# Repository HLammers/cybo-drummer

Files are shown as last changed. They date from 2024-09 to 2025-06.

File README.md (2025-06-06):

<header>


# Cybo-Drummer

**Humanize those drum computers!**

&copy; 2024&ndash;2025 Harm Lammers
</header>
<main>


# Introduction

The situation was that I owned an electronic drum kit and a bunch of drum computers. My dream was to play those drum computers from my drum kit, so I went searching for a way to do just that. It turned out that I couldn&rsquo;t find any software or hardware solution that would give easy-to-use experience with the flexibility to change the mapping as you change a program on a drum module.

That was April 2024, when Cybo-Drummer was born: I decided to develop my own solution. The first prototype on a breadboard took a couple of months build and showed that it could work, but I had a lot to learn: programming in MicroPython, designing PCBs, (re)writing display drivers and a lot more. Also, when Cybo-Drummer started to take shape, it turned out to be a much more complex project than I had anticipated&hellip;

In November 2024 the second prototype was finally ready and I decided to publish it as an open source project. I received several enthausiast responses of people liking the idea, but no one else tried building their own Cybo-Drummer as far as I can tell &ndash; that is no surprise, because the project was still very rough around the edges, with its ad hoc hardware design, no case, a sluggy graphic user interface and an overly complex workflow.

Now, in June 2025 it&rsquo;s time to launch the third prototype. This time everything as been redesigned: new hardware (now based on the more powerful Raspberry Pi Pico 2) in a 3D printed case, an almost completely redesigned user interface (now with icons and a font specially designed for Cybo-Drummer!) and a simplified, yet improved workflow, making it much more intuitive to use, yet virtually as powerful as the previous prototype. It also introduces some neat new features, like velocity layers and tools to easily assign note series to toms and scales/modes and chords to multipad triggers.

With the thrid prototype Cybo-Drummer has reached a state where it does what it has to do. There are still [a few things to be done](#development-roadmap) before reaching version 1.0 (but all things that could be solved with firmware updates). MIDI learn, for example still needs to be refined, better tested and documented. A big inprovement still to come is adding USB MIDI support. Before version 1.23 (released on 31 May 2024) MicroPython didn&rsquo;t support MIDI over USB and even now no one figured out yet how (in MicroPython) to set up the USB MIDI descriptors, such that multiple MIDI ports (over the same USB connection) show up with different port names in the host (see the [MicroPython GitHub discussion](https://github.com/orgs/micropython/discussions/16435) &ndash; if you know how this works, your input is appreciated!)

Are you an experienced drummer with a fascination for synthesized drum sounds? (I&rsquo;ve only started my drumming journey in April 2023 and too much of my time has gone into developing Cybo-Drummer instead of practizing&hellip;) I&rsquo;d love to hear how you experience using Cybo-Drummer. Does it work for you? What would you change? What features are you missing?

> [!NOTE]
> Please use the [issues tab](https://github.com/HLammers/cybo-drummer/issues) to report bug and other issues, or the [discussion tab](https://github.com/HLammers/cybo-drummer/discussions) to discuss anything else.
>
> Of course I&rsquo;m open for collaboration. Just let me know how you think you can contribute!

# Overview

Cybo-Drummer is a MIDI router/mapper with 6 input ports and 6 output ports, specially designed for mapping drum triggers (electronic drum kits&rsquo; modules or brains) to drum computers. Since there is no standard for the MIDI messages sent by drum kits, nor the messages received by drum computers, Cybo-Drummer offers a flexible way of mapping the one to the other.

Cybo-Drummer operates at two distinct levels, each running on its own processor core, as shown by the dashed line in the diagram below:

<div align="center">

</div>

<i>Diagram showing Cybo-Drummer&rsquo;s inner workings. The icons in the corners of the green and orange shapes refer to the respective <a href="USER_MANUAL.md#pages-and-sub-pages">pages</a> in Cybo-Drummer&rsquo;s graphic user interface.</i>

The top level (with the green and orange shapes in the diagram above) manages all definitions, user interaction (buttons and knobs) and the graphic user interface. Some of these definitions are global and the same for all programs (green shapes and arrows), while other definitions (orange shapes and arrows) change when selecting one of the up to 2,600 programs (26 banks of 100 programs).

The bottom level (with the purple shapes and arrows in the diagram above) does its work hidden to the user. Here sits the actual router that routes MIDI data from input ports to output ports &ndash; transformed if neccessary. It is optimized to do as little as possible, to minimize latency.

No interaction takes place between the top and the bottom layer, except if a program is changed or a set-up definition is modified &ndash; this resets the router, rebuilding each route based on the definitions from the top layer.

# Features

## Key Features

* Real-time (low latency) mapping of up to 6 MIDI input devices (drum kits, drum triggers, multipad devices, etc.) to up to 6 MIDI output devices (drum computers, samplers, synthesizers, etc.)
* Combine multiple input devices in a single setup
* Define up to 2,600 programs (26 banks of 100 programs) to easily swich between different output devices and voices
* Combine multiple output devices in one program
* Layer multiple voices from the same or different output devices, including advanced layering techniques based on velocity layers and transition curves
* Set trigger dependency to cc value (a common way for drum modules/brains to distinguish between open and closed hihat)
* Adjust velocity dynamics (threshold, curve, minimum velocity, maximum velocity)
* Adjust how to send note off (off, pulse, fixed delay or a toggle on/off effect)
* Send program change and/or bank select commands to output devices on program change
* Quickly set up toms to the same output device/voice, but with different notes, based on intervals or chords
* Quickly assign notes to the pads of a multipad trigger to different notes, based on scales/modes or to chords (or a combination of both)
* Basic MIDI monitor

## Hardware

* 6 MIDI input ports (5-pin DIN)
* 6 MIDI output ports (5-pin DIN)
* 2.2 inch colour display (220×176 pixels)
* 2 knobs (rotary encoders) and 3 buttons to interact with Cybo-Drummer&rsquo;s graphic user interface
* Power over micro USB or 5V DC power supply
* Option to mount onto drum rack using a standard mounting plate with screw holes spaced 70×100mm (as often used for drum modules/brains and multipads)

# Documentation

For indept documentation on Cybo-Drummer, see the following files:

* [User Manual](USER_MANUAL.md)
* [Building Instructions](BUILDING_INSTRUCTIONS.md)
* [Example Presets](EXAMPLE_PRESETS.md)
* [Development Roadmap](TO_DO.md)

> [!NOTE]
> **<ins>Cybo-Drummer Terminology</ins>**
>
> Since there is no universal terminology used by all manufacturers of electronic drum equipment and drum computers, or that describes all possible combinations of equipment that could be used, a choice had to be made to use the following terminology for Cybo-Drummer:
>
> <table>
> <tr><td><b><i>Input device</i></b></td><td>A drum kit, drum triggers, multipad device, keyboard or other device which exists of multiple <i>triggers</i> and outputs MIDI data</td></tr>
> <tr><td><b><i>Trigger</i></b></td><td>A drum pad, trigger or similar element of an electronic drum kit or other type of <i>input device</i>; a trigger has one or more <i>zones/layers</i></td></tr>
> <tr><td><b><i>Zone/layer</i></b></td><td>A zone or a layer of a <i>trigger</i> which sends a specific MIDI note</td></tr>
> <tr><td><b><i>Multipad device</i></b></td><td>A specific type of <i>input device</i> which combines typically between 4 and 12 pads (<i>triggers</i>) into a single device, which can be used as a compact, table-top or stand mounted drumkit, or used as extension of a regular drum kit; sometimes also called &lsquo;electronic drum pads&rsquo;, &lsquo;electronic percussion controller&rsquo; or &lsquo;sample pads&lsquo; (if it is sample based) or similar</td></tr>
> <tr><td><b><i>Output device</i></b></td><td>A drum computer, sampler, synthesizer or other device which responds to MIDI data</td></tr>
> <tr><td><b><i>Voice</i></b></td><td>A specific sound of an <i>output device</i> which responds to a specific MIDI channel and/or note(s)</td></tr>
> </table>

# Why Cybo-Drummer is Written in MicroPython

A MIDI router/mapper is a time-sensitive application, so why not using the programming language which leads to the fastest possible code (on a Raspberry Pi that would be C++)? Well&hellip; I do am aware that MicroPython is much slower, but I decided to use it anyway, because besides solving my challenge to connect my electronic drum kit to my drum computers, I had a second goal: finally learning how to use Python. You see, I&rsquo;ve used several programming languages over time (starting with BASIC when I was a child, then Turbo Pascal as a teenager in the 90s, later a bit or C/C++ at university, some JavaScript, a lot of VBA and more recently some Arduino code). But never before I found the time to learn Python, while profesionally I&rsquo;m managing a small product development and innovaiton team, with analysts/developers who are using Python as their go-to language &ndash; so I decided it was time to finally master that language as well. This project was a great learning journey!

I spent a lot of time optimizing the code (for speed and memory usage) and it turns out MicroPython on a Raspberry Pi Pico is fast enough after all. Keep in mind MIDI is a 40+ year old protocol, so it is pretty slow by today&rsquo;s standards &ndash; enough time between two MIDI bytes to run a bit of Python code.

To keep latency to a minimum the second core is dedicated to MIDI handling, while the primary core takes care of the graphic user interface and button and rotary encoder input. In that way the second core runs a light loop doing only time-sensitive MIDI routing, while the primary core does all the heavy stuff.

# Licencing

Copyright &copy; 2024&ndash;2025 Harm Lammers

This project is free hardware/software: you can redistribute it and/or modify it under the terms of the GNU General Public License as published by the Free Software Foundation, either version 3 of the License, or (at your option) any later version.

This project is distributed in the hope that it will be useful, but WITHOUT ANY WARRANTY; without even the implied warranty of MERCHANTABILITY or FITNESS FOR A PARTICULAR PURPOSE. See the GNU General Public License for more details.

See [LICENSE](./LICENSE) for the full license text.

The fonts used for the logo and the front panel are Soviet Regular and Soviet X-Expanded, &copy; 2003 Dan Zadorozny &ndash; [Iconian Fonts](https://www.iconian.com), published with the following copyright statement:

> This font may be freely distributed and is free for all non-commercial uses.  This font is e-mailware; that is, if you like it, please e-mail the author at:
>
> iconian@aol.com

</main>

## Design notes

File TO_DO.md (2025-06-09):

<header>


# Cybo-Drummer

**Humanize those drum computers!**

&copy; 2024&ndash;2025 Harm Lammers
</header>
<main>

# Development Roadmap

This file is part of a series of documentation files on Cybo-Drummer:

* [README file](README.md) with brief introduction
* [User Manual](USER_MANUAL.md)
* [Building Instructions](BUILDING_INSTRUCTIONS.md)
* [Example Presets](EXAMPLE_PRESETS.md)
* Development Roadmap (this file)

## Release 0.3.1

*More items from the backlog could get added to the 0.3.1 list if I find the time (or urge), inspiration and right solutions*

- [x] Massively improve monitor screen refresh rate
- [x] Small fixes and improvements
- [ ] Double check, test and document reception of bank select / program change messages
- [ ] Double check, test and document MIDI learn
- [ ] Test batch assign multipad notes velocity layer filter

## Backlog for Future Releases

*Some of the things listed here are more likely than others to ever be implemented &ndash; I&rsquo;m happy to hear your ideas for additional features to be considered!*

### MIDI Handling

- [ ] Adding USB MIDI
- [ ] Distribute MIDI System Real Time Messages (Timing Clock, Start, Continue, Stop)

### MIDI Monitor Improvement

- [ ] Adding MIDI monitor filter options

### MIDI Mapping

- [ ] Adding MIDI CC mapping (doing crazy things, for example with the hihat foot pedal or an express pedal)
- [ ] Rethinking how to deal with choke events, which for some drum modules lead to MIDI note events (2Box, Alesis?) and for others to poly aftertouch/pressure MIDI CC messages (Roland, Yamaha)
- [ ] Adding choke groups which could combine different devices

### User Interface

- [ ] Change active block on other sub-pages where relevant

### PC Editor

- [ ] Building an editor for program definitions, device/trigger/voices definitions and settings on a PC

### Hardware

- [ ] Building a version of Cybo-Drummer with 3 MIDI in ports and 9 MIDI out ports as an alternative for if needed more outputs

</main>

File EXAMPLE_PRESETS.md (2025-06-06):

<header>


# Cybo-Drummer

**Humanize those drum computers!**

&copy; 2024&ndash;2025 Harm Lammers
</header>
<main>

# Example Presets

This file is part of a series of documentation files on Cybo-Drummer:

* [README file](README.md) with brief introduction
* [User Manual](USER_MANUAL.md)
* [Building Instructions](BUILDING_INSTRUCTIONS.md)
* Example Presets (this file)
* [Development Roadmap](TO_DO.md)

## Introduction

Since Cybo-Drummer doesn&rsquo;t make any sound on its own, but merely routes signals from one device to another, it isn&rsquo;t possible to make meaningful factory presets. The presets shared in the [example presets folder](example_presets/) are based on my personal setup, but can be useful as examples. Currently they reflect a baseline for equipment I own, but that will probably evolve over time. I haven&rsquo;t updated them yet, for example, to make use of the old Roland SPD-11 I bought a while ago, and they do not make use yet of the most recently added features.

<!--update version number in the two references to MicroPython below when necessary!-->

> [!TIP]
> To upload the example presets to Cybo-Drummer, follow the same instructions as given for restoring a back-up when [uploading firmware](README.md#uploading-firmware):
>
> * If you haven&rsquo;t before: Install [Python](https://www.python.org/downloads) &ndash; follow the instructions provided [here](https://docs.python.org/3/using/windows.html#windows-full) and **make sure to select &lsquo;Add Python 3.x to PATH&rsquo;**
> * If you haven&rsquo;t before: Download the source code of [MicroPython release v1.25.0](https://github.com/micropython/micropython/releases). (typically the zip version) and unzip it somewhere on your PC
> * In File Explorer go to the micropython-1.25.0\tools\mpremote folder (in the location where you unzipped MicroPython)
> * Right click somewhere in the folder (not on a file) and from the context menu select &lsquo;Open in Terminal&rsquo;
> * If you do it for the first time: type the following to install required Python modules:
>
>   ```
>   pip install pyserial
>   pip instal importlib_metadata
>   ```
>
> * Copy the data_files folder from the [example presets folder](example_presets/) to the micropython-1.24.0\tools\mpremote folder
> * On your PC type `py mpremote.py fs cp -r data_files/ :` **without pressing ENTER** (so not executing it yet)
> * While you keep Cybo-Drummer&rsquo;s TRIGGER button pressed:
>   * Press RESET button on Cybo-Drummer
>   * Press ENTER on your PC to start downloading (backing up) or uploading (restoring)

Below I share some details on the different devices in the example presets, including what I learned so far about setting them up for Cybo-Drummer.

## Input Device: 2Box

My drum kit is a Fame Hybrid Pro, which is produced by 2Box and which is in fact a derivative of 2Box&rsquo;s DrumIt series (it uses the same firmware). The default 2Box input triggers are based on 2Box&rsquo;s default MIDI mapping, with one addition specific to the Fame module: 2Box calls numbers the three cymbals 1, 2 and 3, but which of those are the ride, 1<sup>st</sup> crash and 2<sup>nd</sup> crash seems to be different depending on which type of module.

> [!NOTE]
> By default 2Box modules use MIDI CC 4 to send the position of the hi-hat foot pedal (default setting: 0 = fully open, 127 = fully closed). The hi-hat sends the same MIDI note when open or closed, so the CC 4 value needs to be checked to distinguish between both.

## Output Device: Drumbrute

This device is set up for the factory settings of the Arturia Drumbrute, but since the Drumbrute can&rsquo;t store presets, that only means the default MIDI channel and default note mapping.

> [!NOTE]
> The Arturia Drumbrute doesn&rsquo;t respond to MIDI program change nor bank select messages.

## Output Device: Drumlogue

This device is set up for the factory settings of the Korg Drumlogue, with only one adjustment: the MIDI mode is set to multi-channel 7-2 (on the Drumlogue: SHIFT + GLOBAL &rarr; 7 &rarr; set CH to 7-2), so the Multi Engine can be played tonally. There are 64 Drumlogue presets, linked to the Drumlogue&rsquo;s 64 factory kits.

> [!NOTE]
> The Korg Drumlogue does not respond to MIDI bank select messages, only to program change, but with a twist: MIDI program change value 2 (counting from 1) is kit A1, 3 is kit A2, 18 is B1, etc.

> [!IMPORTANT]
> Make shure to update the Korg Drumlogue to the latest version of the firmware, because version 1.2.0 had a bug which is fixed in version 1.3.0: it didn&rsquo;t respond to MIDI program change values 16, 32, 48, 64, etc. (counting from 0).

## Output Device: LXR-02

This device is set up for the first factory project of the Sonic Portions × Erica Synths LXR-02 (HrtlKits). It assumes the global MIDI channel to be set to the default 1, which the LXR-02 calls 0 (on the LXR-02: SHIFT + CONFIG &rarr; set CH to 0) and the LXR-02 is set to receive program change, control change and note messages (on the LXR-02: SHIFT + CONFIG &rarr; turn DATA knob to scroll to second page &rarr; set MRX to &lsquo;all&rsquo; or &lsquo;PCN&rsquo;).

> [!NOTE]
> The Sonic Portions × Erica Synths LXR-02 responds both to program change and bank select messages: program change messages change patterns, bank select messages (not mentioned in the user manual: MSB only) change kits. Kits are saved per project and it isn&rsquo;t possible to change the project via MIDI.
>
> The LXR-02&rsquo;s manual description of the MIDI implementation and what is saved where (kits, patterns, projects) is rather incomplete. It doesn&rsquo;t indicate, for example, where output routing and FX settings are stored. Searching the internet provides some hints based on other people&rsquo;s experience it&rsquo;s stored with kits, but I haven&rsquo;t yet tested it myself.  

> [!CAUTION]
> Make sure not to assign one of the LXR-02&rsquo;s voices to same MIDI channel which is assigned to the LXR-02&rsquo;s global channel, because triggering that channel will trigger the selected voice on the LXR-02.

> [!TIP]
> Best is to prepare a special project to use LXR-02 effectively with Cybo-Drummer:
>
> * Initiate a new project: press LOAD + PROJECT &rarr; select an EMPTY project &rarr; press DATA knob
> * Set kit change mode to &lsquo;off&rsquo; to separate kits from patterns: press SHIFT + CONFIG &rarr; turn DATA knob to scroll to third page &rarr; set KCM to &lsquo;off&rsquo;
> * In pattern 1 (the default pattern after initiating a new project), assign voices to MIDI channels 2 to 8 (channel 0 is used as global channel, so triggering that channel will trigger the selected voice on the LXR-02) and set each voice to respond any note (allowing to tune it from Cybo-Drummer or to play it tonally):
>   * Press VOICE &rarr; press MIX &rarr; turn DATA knob to scroll to second page
>   * Press DRUM1 button (below sliders) &rarr; set CH to 2 and set NTE to &lsquo;any&rsquo;
>   * Press DRUM2 button (below sliders) &rarr; set CH to 3 and set NTE to &lsquo;any&rsquo;
>   * Press DRUM3 button (below sliders) &rarr; set CH to 4 and set NTE to &lsquo;any&rsquo;
>   * Press SNARE button (below sliders) &rarr; set CH to 5 and set NTE to &lsquo;any&rsquo;
>   * Press CLP/CYM button (below sliders) &rarr; set CH to 6 and set NTE to &lsquo;any&rsquo;
>   * Press CL HH button (below sliders) &rarr; set CH to 7 and set NTE to &lsquo;any&rsquo;
>   * Press OP HH button (below sliders) &rarr; set CH to 8 and set NTE to &lsquo;any&rsquo;
> * Save project:
>   * Press SAVE + PROJECT &rarr; press DATA knob
>   * Turn DATA knob to select &lsquo;Y&rsquo; &rarr; press DATA knob
>   * Change name: Turn DATA knob to select character to change &rarr; press DATA knob &rarr; turn DATA knob to select character &rarr; press DATA knob to confirm; &rarr; finish editing by selecting &lsquo;ok&rsquo; (turn DATA knob clockwise until it is selected) and pressing DATA knob
> * Turn off the LXR-02, take out the SD card and use a PC to copy the kits (files with .SND extension) you&rsquo;d like to use into the newly created project folder (called PROJ##, where # is the project number) and rename them so they start with &lsquo;01-&rsquo; to &lsquo;63-&rsquo;
> * Put the SD card back into the LXR-02 and load the project: press LOAD + PROJECT &rarr; select the project &rarr; press DATA knob

## Output Device: Volca Drum

This device is set up for a Korg Volca Drum in default split channel mode (in which parts 1 to 6 are assigned to MIDI channels 1 to 6 respectively). There are 16 Volca Drum programs, linked to program 1 to 16 of the Volca Drum.

> [!NOTE]
> The Volca drum does not respond to MIDI bank select messages, only to program change. Program changes messages 1 to 16 (counting from 1) select Volca Drum programs 1 to 16, each of which has a sequence and a kit assigned, so to make best use of the Volca Drum with Cybo-Drummer, assign each kit to a separate program.

</main>

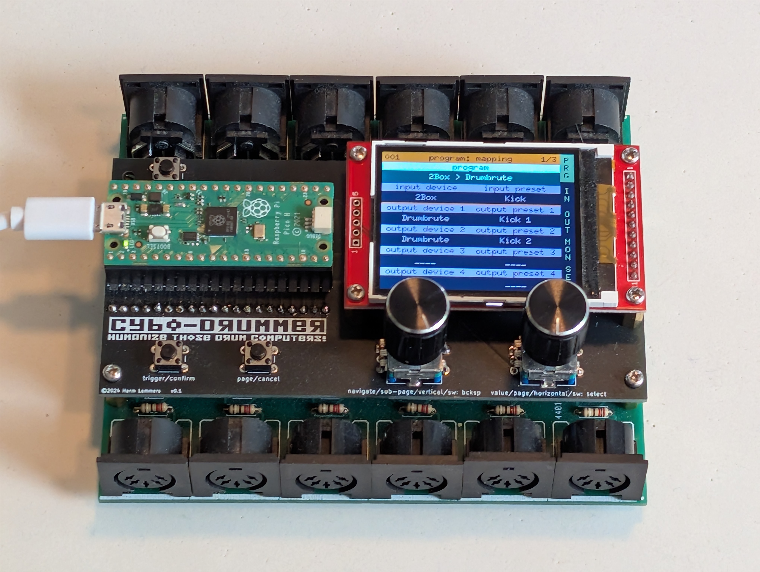
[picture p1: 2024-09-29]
images/cybo-drummer_v0.1.jpg

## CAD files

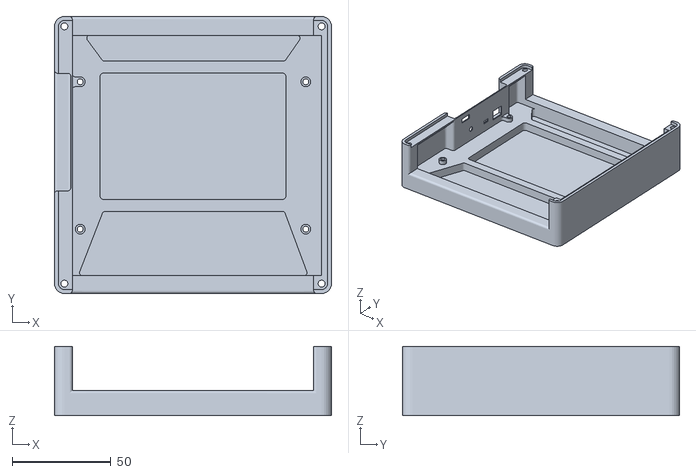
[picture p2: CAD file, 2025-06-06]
stl_files/Cybo-Drummer case bottom part v3.0.stl
140.0 x 140.0 x 34.9

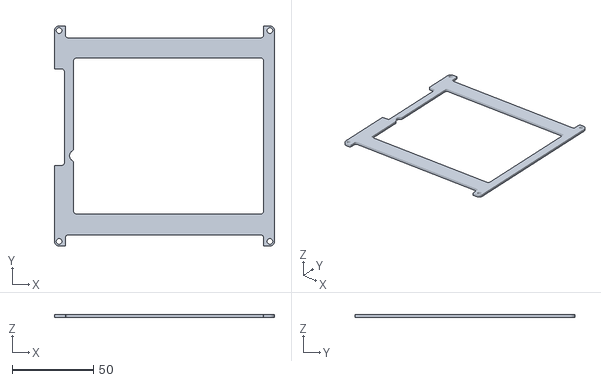
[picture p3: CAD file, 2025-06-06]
stl_files/Cybo-Drummer case top part v3.0.stl
135.6 x 135.6 x 2.10

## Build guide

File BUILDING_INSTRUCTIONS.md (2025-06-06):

<header>


# Cybo-Drummer

**Humanize those drum computers!**

&copy; 2024&ndash;2025 Harm Lammers
</header>
<main>

# Building Instructions

This file is part of a series of documentation files on Cybo-Drummer:

* [README file](README.md) with brief introduction
* [User Manual](USER_MANUAL.md)
* Building Instructions (this file)
* [Example Presets](EXAMPLE_PRESETS.md)
* [Development Roadmap](TO_DO.md)

# Introduction

The first Cybo-Drummer prototypes were building upon an existing design by [diyelectromusic (Kevin)](https://diyelectromusic.com), using that design as the bottom PCB with the MIDI ports ([Raspberry Pi Pico Multi MIDI Router](https://diyelectromusic.com/2022/09/19/raspberry-pi-pico-multi-midi-router-part-5)), adding a second PCB on top which connected to the Raspberry Pi Pico headers on Kevin&rsquo;s PCB.

Version 0.3 is a completely new hardware design, still taking inspiration from Kevin&rsquo;s design, but much better tailored to Cybo-Drummer&rsquo;s requirements. It also marks a switch from the original Raspberry Pi Pico to the Raspberry Pi Pico 2, which, with about twice as much RAM, solves a lot of issues which were related to running into memory limitations.

***I have no intention to sell Cybo-Drummer as a fully assembled product, nor as DIY kit.*** &ndash; I might change my mind in the future, but for now that doesn&rsquo;t seem like a realistic idea, next to a full-time job and a family (especially because I expect it to be a very niche product &ndash; unless a change in trend occurs and many more drummers become interested again in electronic drums as an instrument of its own &ndash; like in the 1980s &ndash; instead of a means to simulate acoustic drums). Nevertheless: if you think you can convince me to change my mind, feel free to try!

> [!IMPORTANT]
> This file provides building instructions for version 0.3 of the Cybo-Drummer hardware. Hardware and software versions before version 0.3 are not compatible with version 0.3 (and vice versa).

## Hardware

Building the Cybo-Drummer hardware only requires basic soldering skills (it uses only though-hole components). The PCBs can be ordered relatively cheaply from Chinese PCB services like [JLCPCB](https://jlcpcb.com) (no affiliate). The front panel is a PCB as well, the rest of the case can be 3D printed.

### BOM (Bill of Materials)

* Zip files with Gerber files for the top PCB, bottom PCB can be found in the [Gerber files folder](gerber_files/) &ndash; order them from your favourite PCB service (I&rsquo;ve successfully used these to order PCBs from [JLCPCB](https://jlcpcb.com), which is no affiliate)
* The front panel is also a PCB, Gerber files for which can be found in the [Gerber files folder](gerber_files/) as well
* STL files for the two parts of the 3D printed case (top and bottom) can be found in the [STL files folder](stl_files/) &ndash; I&rsquo;ve printed successfully on an old (highly modified) Creality Ender 3 Pro printer, but they should work on any printer, or you can order them from a printing service

> [!NOTE]
> Schematics for the top and bottom PCBs can be found in the [schematics folder](schematics/).

#### Bottom PCB

* Cybo-Drummer bottom PCB v0.3.2 (in [Gerber files folder](gerber_files/))
* 6× H11L1 optocoupler
* 6× 470&Omega; resistor
* 6× 220&Omega; resistor
* 6× 33&Omega; resistor
* 6× 10&Omega; resistor
* 6× 1N914 or 1N4148 diode
* 1× 1N5817 diode
* 6× 100&mu;F ceramic capacitor with 5mm spacing
* 1× [SK-12D07(1P2T) switch](https://www.tinytronics.nl/en/switches/manual-switches/slide-switches/small-switch-90-degrees-extra-strong)
* 1× [6×6×6mm momentary tactile button](https://nl.aliexpress.com/item/10000056364450.html)
* 1× [DC-044 5.5×2.1 DC jack](https://www.tinytronics.nl/en/cables-and-connectors/connectors/dc-jack/dc-jack-plastic-5.5mm-female-dc-044)
* 12× [DS-5-01 5-pin DIN PCB mount socket](https://nl.aliexpress.com/item/1005005377343340.html) (double-check the footprint on the PCB, because there are similar sockets on the market with slightly different spacings of the soldering pins!)
* 1×5 female pin header socket (tip: shorten a longer socket)
* 1×18 female pin header socket (tip: shorten a longer socket)

#### Top PCB

* Cybo-Drummer top PCB v0.3.1 in ([Gerber files folder](gerber_files/))
* Raspberry Pi Pico 2 without headers (from version 0.3 Cybo-Drummer is no longer compatible with the original Raspberry Pi Pico &ndash; it requires mark 2!)
* [2.2" 176×220 TFT display board with ILI9225 driver](http://www.lcdwiki.com/2.2inch_Arduino_SPI_Module_ILI9225_SKU:MAR2201) &ndash; sold for example [here](https://www.tinytronics.nl/en/displays/tft/2.2-inch-tft-display-176*220-pixels)
* 8× 10k&Omega; resistor
* 4x 10nF ceramic capacitor with 5mm spacing
* 2× EC11 rotary encoder
* 3× [12×12×7.3mm 4-pin THT momentary tactile button](https://www.tinytronics.nl/en/switches/manual-switches/pcb-switches/tactile-pushbutton-switch-momentary-4pin-12*12*7.3mm)
* 2× 1×5 male pin header
* 1× 1×18 male pin header
* 4× 1×1 male header spacers (only the plastic part with the metal pin removed)

#### Case

* Cybo-Drummer case bottom part v3.0 (in [STL files folder](stl_files/))
* Cybo-Drummer case top part v3.0 (in [STL files folder](stl_files/))
* Cybo-Drummer front panel PCB v0.3.1 (in [Gerber files folder](gerber_files/))
* 4× M4×6×6 brass heat-set inserts (not necessarily needed if you have no intention to use a mounting plate)

#### Final Assembly

* 4× M2.5×5 pan head screw
* 4× M2.5×12 pan head screw
* 4× M2.5×11 spacers
* 4× M3×35 hex socket head cap screw (black)
* 4× M3 bolt
* 1× [LC5-3 5mm LED light guide cap](https://nl.aliexpress.com/item/1005008732919698.html) (general style)
* 3× [Round 11.×5.7mm button cap](https://www.tinytronics.nl/en/components/knobs,-caps-and-covers/button-cap-for-tactile-pushbutton-switch-momentary-12x12x7.3mm-white)
* 2× [15×17mm rotary encoder / potentiometer knob](https://www.tinytronics.nl/en/components/knobs,-caps-and-covers/potmeter-knob-black)
<br clear="right"/>

### Building Instructions

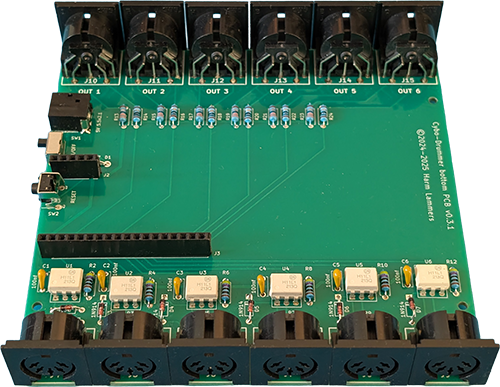
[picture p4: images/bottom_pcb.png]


#### Bottom PCB

Assemble the top PCB by following the following steps:

  1. Solder all **resistors** and **diodes**
  2. Solder all **H11L1 optocouplers** (U1 to U6)
  3. Solder all **capacitors**
  4. Solder the **on/off switch** (SW1)
  5. Solder the **reset button** (SW2) and the **DC power socket** (J1)
  6. Solder the **1×5 and 1×18 female pin header sockets** (J2 and J3)
  7. Solder all the **DIN MIDI sockets** (J4 to J15)

> [!IMPORTANT]
> Diodes need to be oriented correctly: they have a line marking their cathode (negative) side, which should match the similar marking printed on the PCB.
>
> The H11L1 octocouples need to be oriented correctly as well: [pin 1](https://en.wikipedia.org/wiki/Dual_in-line_package#Orientation_and_lead_numbering) is recognizable on the PCB as a square soldering pad. The print on the PCB also shows the identifying notch as can often been found on the octocoupler package (if the package doesn&rsquo;t have a notch, it would have a dot indicating pin 1).

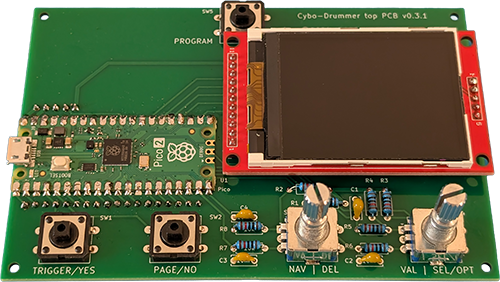
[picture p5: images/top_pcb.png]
<br clear="right"/>
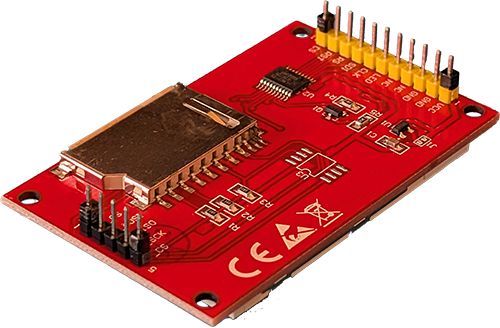
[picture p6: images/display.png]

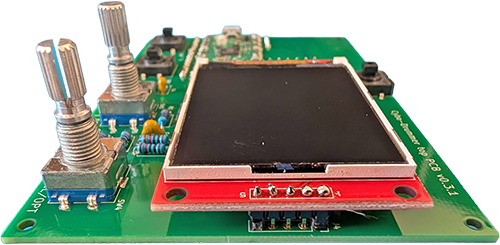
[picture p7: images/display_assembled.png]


#### Top PCB

Assemble the top PCB by following the following steps:

  1. Solder the **Raspberry Pi Pico 2** directly onto the Cybo-Drummer top PCB, without any headers (those would add too much height)
  2. Solder all **resistors**
  3. Solder all **capacitors**
  4. Solder all **buttons** (SW1, SW2, SW5)
  5. Prepare the display by:
     1. soldering an additional **1×5 male pin header to the display board** (these are only used to fixate the display board to the Cybo-Drummer top PCB)
     2. add the 4 **1×1 male header spacers to the male pin headers on the display board** as can be seen on the photo on the right
  6. Solder the **display board** directly onto the Cybo-Drummer top PCB, without female headers (but with the additional spacers!)
  7. Solder the **rotary encoders** (SW3, SW4)
  8. Solder the second **1×5 male pin header** and the **1×18 male pin header *onto the bottom of the PCB*** (J1, J2)

The result should look like on the photo on the right.

> [!TIP]
> Use a few short pin headers to keep the Raspberry Pi Pico 2 perfectly aligned before fixating the Pico by soldering each corner. Then remove the pin headers and finishing soldering each castellated pad.

* Plug the second board to Pico header sockets of the first board and fix them together using four spacers
* Plug the Raspberry Pi Pico into the 2x 20-pin header sockets on the second board

#### 3D Print Case

* The case can be printed in PLA (that&rsquo;s what I&rsquo;ve used for the prototypes so far), but if used, stored or transported in hot environments I advise a more heat-resistant material like PETG or ABS
* No printing supports are needed, but that might cause some obstructions in recessed screw holes in the bottom of the case &ndash; use for example a small screwdriver to clean the holes before assembling the case
* Insert the brass inserts into the four holes in the bottom of the case which do not go through all the way (see for example [this website](https://www.cnckitchen.com/blog/tipps-amp-tricks-fr-gewindeeinstze-im-3d-druck-3awey) for instructions on how to insert brass heat-set inserts) &ndash; this step might be skipped if you have intention to use a mounting plate
<br clear="right"/>

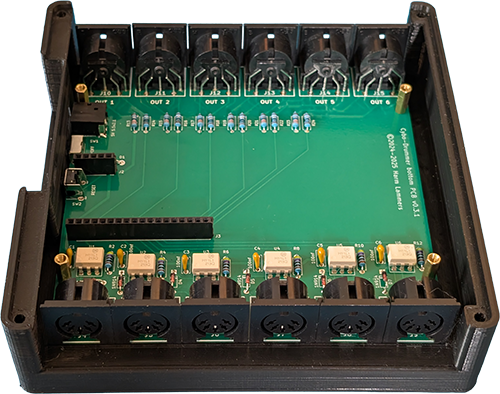
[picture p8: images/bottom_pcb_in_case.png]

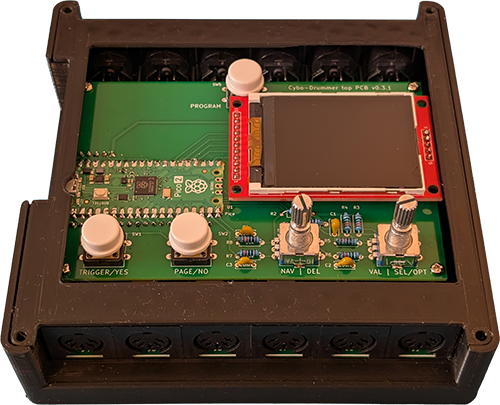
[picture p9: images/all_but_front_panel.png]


#### Assembly

1. Place the bottom PCB into the bottom part of the case, such that the switches and power socket on the left side align with the holes in the side of the case and the four holes in the bottom PCB
2. Insert the four M2.5×12 pan head screws through the bottom of the case, such that they go through the holes in the bottom PCB and fasten them with the four M2.5×11 spacers
3. Insert the top PCB on top of the bottom PCB, such that the top PCB&rsquo;s male pin headers insert into the bottom PCB&rsquo;s female pin headers and the holes in the top PCB align with the spacers
4. Use the four M2.5×5 pan head screws to fasten the top PCB into the spacers
5. Click the three button caps onto the TRIGGER/YES, PAGE/NO and PROGRAM buttons
6. Insert the top part of the case, such that it follows the shape of the top of the case and the round holes are aligned with the holes in the corner of the case
7. Insert the LED light guide cap into the front panel PCB (into the hole between &lsquo;USB&rsquo; and &lsquo;TRIGGER/YES&rsquo;)
8. Place the front panel PCB on to of the case such that all the holes align with the screen, buttons, rotary encoders and holes in the corner of the case
9. Insert the four M3×35 hex socket head cap screws from the bottom through the corners of the case and fasten them with the four M3 bolts from the bottom of the case (the bolts should sink into the bottom of the case)
10. Slide the two knobs over the rotary encoders

## Software

The easiest way to install the software is by downloading the [latest firmware](https://github.com/HLammers/cybo-drummer/releases) as a single file and uploading it the Cybo-Drummer, but it can be run directly from source as well.

> [!NOTE]
> Cybo-Drummer offers a couple of key combinations specifically for debugging and firmware upload purposes:
>
> <table>
> <tr><td><b>RESET</b></td><td>Resets Cybo-Drummer</td></tr>
> <tr><td><b>RESET + TRIGGER</b></td><td>Avoids starting Cybo-Drummer&rsquo;s main loops <i>(the user interface and the router) and allows a PC to interact over USB &ndash; press the RESET button while keeping the TRIGGER button pressed until the PC made a connection (after the Raspberry Pi Pico&rsquo;s LED flashed)</i></td></tr>
> <tr><td><b>RESET + TRIGGER + PAGE</b></td><td>Starts bootloader<i> (show Cybo-Drummer as drive called RP2350 on your PC for uploading firmware) &ndash; press the RESET while keeping the TRIGGER and PAGE buttons pressed until the RP2350 drive appears on your PC (after the Raspberry Pi Pico&rsquo;s LED flashed) &ndash; this is an alternative to BOOTSEL + RESET for when the BOOTSEL button is hidden behind the front panel</i></td></tr>
> </table>

### Uploading Firmware

* Back up your user settings (see warning below)
* Download the [latest firmware release](https://github.com/HLammers/cybo-drummer/releases) (.uf2 file)
* Connect Cybo-Drummer with a USB cable to your PC of choice (running Windows, Linux or MacOS)
* Do one of the following to make the Cybo-Drummer appear as a drive called RP2350 on your PC:
  * Press the RESET button and wait for the LED on the Raspberry Pi Pico to turn on; in the 1 second the LED is on, press and keep the TRIGGER and PAGE buttons pressed until the RP2350 drive appears on your PC
  * Keep the Raspberry Pi Pico&rsquo;s BOOTSEL button pressed and keep the RESET button pressed until the RP2350 drive appears on your PC
* Copy the firmware file to the PRI-RP2 drive &ndash; Cybo-Drummer will automatically restart with the new firmware
* Restore your user settings (see warning box below)

<!--update version number in the three references to MicroPython below when necessary, as well as in the EXAMPLE_PRESETS.md file!-->

> [!CAUTION]
> ***Uploading new firmware might delete your user settings (including user-defined programs) and reinstate default values!***
>
> User settings are stored internally in a file folder called data_files. Currently the easiest way To back-up (download) or restore (upload) the file is by following these steps (assuming you&rsquo;re using a Windows PC):
>
> * If you haven&rsquo;t before: Install [Python](https://www.python.org/downloads) &ndash; follow the instructions provided [here](https://docs.python.org/3/using/windows.html#windows-full) and **make sure to select &lsquo;Add Python 3.x to PATH&rsquo;**
> * If you haven&rsquo;t before: Download the source code of [MicroPython release v1.25.0](https://github.com/micropython/micropython/releases). (typically the zip version) and unzip it somewhere on your PC
> * In File Explorer go to the micropython-1.25.0\tools\mpremote folder (in the location where you unzipped MicroPython)
> * Right click somewhere in the folder (not on a file) and from the context menu select &lsquo;Open in Terminal&rsquo;
> * If you do it for the first time: type the following to install required Python modules:
>
>   ```
>   pip install pyserial
>   pip instal importlib_metadata
>   ```
>
> * *To back up user settings:*
>   * On your PC type `py mpremote.py fs cp -r :data_files/ .` **without pressing ENTER** (so not executing it yet)
> * *To restore user settings:*
>   * Copy your data_files to the micropython-1.25.0\tools\mpremote folder
>   * On your PC type `py mpremote.py fs cp -r data_files/ :` **without pressing ENTER** (so not executing it yet)
> * While you keep Cybo-Drummer&rsquo;s TRIGGER button pressed:
>   * Press RESET button on Cybo-Drummer
>   * Press ENTER on your PC to start downloading (backing up) or uploading (restoring)

### Running From Source

It is possible to run Cybo-Drummer from source by uploading the content from the [src folder](src/) to the Raspberry Pi Pico running [stock MicroPython](https://micropython.org/download/RPI_PICO).

Keep in mind that when running from source (instead of frozen into firmware), Cybo-Drummer takes more time to boot. To resolve this while playing around with the code it is also possible to freeze only part of the source code, following the instructions under [building firmware from source](#building-firmware-from-source).

### Building Firmware From Source

So far I haven&rsquo;t found an easy way to build MicroPython on a Windows PC, only on a device running Debian Linux, so I&rsquo;m using a Raspberry Pi 400 for this purpose, but any Raspberry Pi 4 or 5 running Raspberry OS will do.

To build Cybo-Drummer follow these steps:

* *First time you build Cybo-Drummer*: In the Raspberry Pi console type (this creates a /home/pi/pico folder to with the MicroPython source code):

```
cd ~/
mkdir pico
cd pico
git clone https://github.com/micropython/micropython.git --branch master
cd micropython
git checkout v1.25.0
sudo apt update
sudo apt install cmake gcc-arm-none-eabi libnewlib-arm-none-eabi build-essential
make -C mpy-cross
```

* Copy all files from the [src folder](src/) except screen_log.py and the data_files folder to the /home/pi/pico/micropython/mpy-cross/ folder
* Remove all files (from previous Cybo-Drummer builds) from the /home/pi/pico/micropython/ports/rp2/modules folder, except the default files main.py, _boot.py, _boot_fat.py and rp2.py
* In the Raspberry Pi console type the following to pre-compile each .py file you just copied (except main.py, which needs to be frozen as a .py file), delete them afterwards (the `-O3` option, which stands for optimization level 3, makes sure `__debug__` is False and all debugging code is left out) and move results to the /home/pi/pico/micropython/ports/rp2/modules folder (to freeze them into the firmware):

```
cd ~/pico/micropython/mpy-cross
for f in *.py; do [ "$f" != "main.py" ] && python3 -m mpy_cross -march=armv7emsp -O3 $f; [ "$f" != "main.py" ] && rm $f; done
mv {*.mpy,*.py} ../ports/rp2/modules/
```

* Now to build the firmware type in the Raspberry Pi console:

```
cd ~/pico/micropython/ports/rp2
make BOARD=RPI_PICO2 submodules
make BOARD=RPI_PICO2 clean
make BOARD=RPI_PICO2
```

* The freshly built firmware is stored as /home/pi/pico/micropython/ports/rp2/build-RPI_PICO2/firmware.uf2

> [!TIP]
> An easy way to copy the Cybo-Drummer source code from a PC to the modules folder on a Raspberry Pi is by [setting up Samba on the Raspberry Pi](https://fernandezvictor.medium.com/raspberry-pi-as-samba-server-to-create-shared-folder-between-computers-cdea979092b8) and turn the home/pi/pico folder into a shared folder.

</main>

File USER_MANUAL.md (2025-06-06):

<header>


# Cybo-Drummer

**Humanize those drum computers!**

&copy; 2024&ndash;2025 Harm Lammers
</header>
<main>

# User Manual

This file is part of a series of documentation files on Cybo-Drummer:

* [README file](README.md) with brief introduction
* User Manual (this file)
* [Building Instructions](BUILDING_INSTRUCTIONS.md)
* [Example Presets](EXAMPLE_PRESETS.md)
* [Development Roadmap](TO_DO.md)

> [!NOTE]
> **<ins>Cybo-Drummer Terminology</ins>**
>
> Since there is no universal terminology used by all manufacturers of electronic drum equipment and drum computers, or that describes all possible combinations of equipment that could be used, a choice had to be made to use the following terminology for Cybo-Drummer:
>
> <table>
> <tr><td><b><i>Input device</i></b></td><td>A drum kit, drum triggers, multipad device, keyboard or other device which exists of multiple <i>triggers</i> and outputs MIDI data</td></tr>
> <tr><td><b><i>Trigger</i></b></td><td>A drum pad, trigger or similar element of an electronic drum kit or other type of <i>input device</i>; a trigger has one or more <i>zones/layers</i></td></tr>
> <tr><td><b><i>Zone/layer</i></b></td><td>A zone or a layer of a <i>trigger</i> which sends a specific MIDI note</td></tr>
> <tr><td><b><i>Multipad device</i></b></td><td>A specific type of <i>input device</i> which combines typically between 4 and 12 pads (<i>triggers</i>) into a single device, which can be used as a compact, table-top or stand mounted drumkit, or used as extension of a regular drum kit; sometimes also called &lsquo;electronic drum pads&rsquo;, &lsquo;electronic percussion controller&rsquo; or &lsquo;sample pads&lsquo; (if it is sample based) or similar</td></tr>
> <tr><td><b><i>Output device</i></b></td><td>A drum computer, sampler, synthesizer or other device which responds to MIDI data</td></tr>
> <tr><td><b><i>Voice</i></b></td><td>A specific sound of an <i>output device</i> which responds to a specific MIDI channel and/or note(s)</td></tr>
> </table>

## Overview



### Connections

Cybo-Drummer has the following physical connections:

* **Near side:**
  * Six 5-pin MIDI input ports to connect input devices
* **Far side:**
  * Six 5-pin MIDI output ports to connect output devices
* **Left side:**
  * Micro USB port &ndash; currently only used for updating the firmware (or as alternative power supply)
  * 5V power supply socket, for a DC adapter using a 5.5×2.1 center positive plug (300mA is certainly enough, 200mA will probably work as well)
<br clear=right>

### Buttons & Knobs

To control Cybo-Drummer&rsquo;s user interface it has three buttons and two rotary encoders on the front panel and a button and a switch on the left side. These have the following functions:

* **PROGRAM**
  * *Press:*
    * *Usually:*&ensp;Open pop-up to [select bank and program](#selecting-a-bank-and-a-program)
    * *If the selected program has unsaved changes:*&ensp;Open [pop-up](#saving-a-program) to select bank and program number to save to
* **TRIGGER/YES:**
  * *Short press:*
    * *Usually:*&ensp;Trigger the selected zone/layer of the selected trigger
    * *In a pop-up:*&ensp;Confirm changes and close pop-up
  * *Long press:*&ensp;Open pop-up to [select trigger and zone/layer](#selecting-a-trigger)
* **PAGE/NO:**
  * *Press:*
    * *Usually:*&ensp;Toggle page select mode on or off
    * *In a pop-up:*&ensp;Cancel changes and close pop-up
* **NAV/&varr; | DEL:**
  * *Turn:*
    * *Usually:*&ensp;Navigate / select active block
    * *In page select mode:*&ensp;Select sub-page (see [Pages and Sub-Pages](#pages-and-sub-pages))
    * *On the [trigger matrix](#trigger-matrix) page or in [text edit pop-up](#text-edit-pop-up):*&ensp;Move selection up or down
  * *Press:*
    * *Usually:*&ensp;Clear selection to blank or default value (if applicable)
    * *In page select mode:*&ensp;Select sub-page (see [Pages and Sub-Pages](#pages-and-sub-pages))
    * *On [program](#program-1) selection or [voice](#voice) name block:*&ensp;Delete program/voice (a [confirmation pop-up](#confirmation-pop-ups) will show)
* **VAL/&harr; | SEL/OPT:**
  * *Turn:*
    * *Usually:*&ensp;Change value of active block
    * *On [trigger matrix](#trigger-matrix) page or in [text edit pop-up](#text-edit-pop-up):*&ensp;Move selection left or right
  * *Short press:*
    * *On changed but not yet confirmed value:*&ensp;Confirm value and process the change (a block turns purple if it has changed but not yet confirmed value)
    * *On [program](#program-1) selection or [voice](#voice) name block:*&ensp;Open options menu pop-up (press twice if the value was changed, but not yet confirmed: the first time will confirm it, the second time triggers rename or options menu)
    * *On button block:*&ensp;Press/execute button
  * *Long press:*
    * *On [trigger matrix](#matrix-cell-1-to-64) page matrix cell:* [**Add all triggers of a multipad device at once**](#adding-all-triggers-of-a-multipad-device-at-once) to the trigger matrix configuration

* **ON/OFF:** *(left side)*
  * Switch Cybo-Drummer on or off when powered with a 5V power supply &ndash; when powered via USB the ON/OFF switch has no effect
* **RESET:** *(left side)*
  * *Press:*&ensp;Resets Cybo-Drummer (has the same effect as turning off and on again)
<br clear=right>

### Display

#### Layout

The user interface displayed on the 2.2-inch TFT screen is organized as follows:

* **Page tabs:**&ensp;The right edge of the screen shows which of the six [pages](#pages-and-sub-pages) is selected
* **Title bar:**&ensp;The top edge of screen shows a title bar, consisting of three elements:
  * On the left the active bank (A to Z) and program number (0 to 99) are always visible (an asterisk is shown behind the number if the program has unsaved changes)
  * Centrally the title of the active sub-page is shown
  * On the right the number of the active sub-page and how many sub-pages the active page has
* **Sub-page:**&ensp;The remainder of the screen is taken by the sub-page itself
  * **Blocks:**&ensp;All sub-pages except monitor pages are structured in blocks which can be selected to enter input; the active block is highlighted using a dark and light sea green colour
  * **Info bar:**&ensp;All sub-pages except monitor pages have an info bar at the bottom, which shows additional information about the selected block

#### Pages and Sub-Pages

Cybo-Drummer&rsquo;s user interface is organized in six pages:

* &emsp;**program & trigger matrix:**&ensp;Select and edit routing programs
* &emsp;**trigger matrix:**&ensp;Assign output triggers to a visual matrix representation
* &emsp;**input:**&ensp;Edit input port assignments, input device setting, input trigger settings and input preset settings
* &emsp;**output:**&ensp;Edit output port assignments, output device setting, output trigger settings and output preset settings
* &emsp;**tools:**&ensp;Quickly assign toms and multipad triggers based on scales, intervals, chords, etc.
* &emsp;**monitor:**&ensp;Show router and MIDI monitors
* &emsp;**settings:**&ensp;Adjust global settings


To change pages and sub-pages:
1. press the PAGE button &#9312; to enter page select mode
2. Turn the VAL/&harr; knob &#9313; to change the page or the NAV/&varr; knob &#9314; to change the sub-page
3. Press the PAGE button &#9312;, the DEL knob &#9315; or the SEL/OPT knob &#9316;

While in page select mode the page tabs and title bar are highlighted in dark and light sea green.

> [!IMPORTANT]
> The [program](#program) page () and the [tools](#tools) page () do not save automatically, all other pages do (after confirming a changed value). An asterisk will show behind the active program number if there are unsaved changes. Press the PROGRAM button when there are unsaved changes to [save a program](#saving-a-program).

## Getting Started

The general workflow of using Cybo-Drummer follows its inner workings as shown in the diagram below.

* Start by [organizing input triggers on the trigger matrix](#organizing-input-triggers-on-the-trigger-matrix);
* then [set up input devices](#setting-up-an-input-device) and [assign triggers](#assigning-triggers-to-an-input-device);
* and [set up output devices](#setting-up-an-output-device) and their [voices](#setting-up-an-output-devices-voices).
* Now the global setup is finished it is time to [set up programs](#setting-up-a-program).
* Once programs are defined it is time to use Cybo-Drummer for your drumming sessions by [recalling your desired programs](#selecting-a-bank-and-a-program.)

<div align="center">

</div>

<i>Diagram showing Cybo-Drummer&rsquo;s inner workings. Green shapes and arrows represent the global definitions, which are the same no matter which program is selected; orange shapes and arrows represent programs, of which up to 2,600 (26 banks of 100 programs) can be stored and recalled; purple shapes and arrows represent the completely separate layer (running on its own processor core) which does the actual real time routing and transformation. The icons in the corners of the green and orange shapes refer to the respective <a href="#pages-and-sub-pages">pages</a> in Cybo-Drummer&rsquo;s graphic user interface.</i>
<br clear=right>

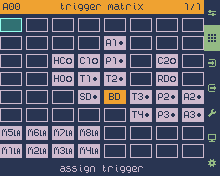
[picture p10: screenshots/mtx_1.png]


### Organizing Input Triggers on the Trigger Matrix

<i>The image on the right shows an example of a trigger matrix setup including a drum kit, a 2×8 multipad and a couple of additional trigger pads</i>

The very first step to set up Cybo-Drummer is setting up the [trigger matrix](#trigger-matrix) to (roughly) represent your drum setup. Each cell in the matrix can represent a trigger, which can have multiple [zones or layers](#triggers-and-zoneslayers) (for example ride cymbal with an edge, bow, bell and choke zone &ndash; not all of these need to be in use). Make sure to include all triggers you&rsquo;d like to use with Cybo-Drummer, because the same trigger matrix is used to [select a trigger](#selecting-a-trigger), so triggers which are not assigned to the trigger matrix cannot be selected for editing or assignment that way.

> [!NOTE]
> Number your toms from high to low for the [toms assignment tool](#assigning-notes-to-toms) to work properly (so T1 is your highest tom, which is the leftmost tom on a typical right-handed setup).
<br clear=right>



#### Adding a Single Trigger

1. Go to the [trigger matrix](#trigger-matrix) page ()
2. Select the [trigger matrix cell](#matrix-cell-1-to-64) to which you&rsquo;d like to assign a trigger
3. Short press the SEL/OPT knob &#9312; to show a trigger selection pop-up
4. **Assign trigger** is selected by default &ndash; turn the VAL/&harr; knob &#9313; to choose the trigger to assign
5. *Optionally* turn the NAV/&varr; knob &#9314; to select **set active zone/layer** and turn the VAL/&harr; knob &#9313; to select an option (this only affects the active trigger setting, not the stored trigger matrix configuration)
6. Press the SEL/OPT knob &#9312; or the YES button &#9315; to confirm (or press the NO button &#9316; to cancel without changes)

> [!NOTE]
> If you assign a trigger which is already assigned to a different cell, it will be removed from its old position on the trigger matrix, so you&rsquo;re essentially moving it to a new location.
<br clear=right>



#### Adding All Triggers of a Multipad Device at Once

<ol>
<li>Go to the <a href="#trigger-matrix">trigger matrix</a> page ()</li>
<li>Select the <a href="#matrix-cell-1-to-64">trigger matrix cell</a> to which you&rsquo;d like to assign the top-left corner of the multipad</li>
<li>Long press the SEL/OPT knob &#9312; to show a multipad selection pop-up</li>
<li>Turn the VAL/&harr; knob &#9313; to choose the mutlipad layout which best matches your multipad device:<table>
<tr><td><b>Layout Name</b></td><td><b>Layout</b></td><td><b>Examples of Devices</b></td></tr>
<tr><td>4 pads 2x2</td><td><table align="center">
<tr><td>3</td><td>4</td></tr>
<tr><td>1</td><td>2</td></tr>
</table></td><td>Alesis SamplePad 4, KAT KTMP1</td></tr>
<tr><td>6 pads 2x3</td><td><table align="center">
<tr><td>4</td><td>5</td><td>6</td></tr>
<tr><td>1</td><td>2</td><td>3</td></tr>
</table></td><td>Hampback ST-5, Nord Drum 3P</td></tr>
<tr><td>8 pads 2x4</td><td><table align="center">
<tr><td>5</td><td>6</td><td>7</td><td>8</td></tr>
<tr><td>1</td><td>2</td><td>3</td><td>4</td></tr>
</table></td><td>Alesis PerformancePad, Carlsbro OKTA-A, NUX DP-2000, Roland Octapad / SPD-8 / SPD-11 / SPD-20 / SPD-20 PRO / SPD-30</td></tr>
<tr><td>8 pads 2x3+2</td><td><table align="center">
<tr><td>7</td><td> </td><td>8</td></tr>
<tr><td>4</td><td>5</td><td>6</td></tr>
<tr><td>1</td><td>2</td><td>3</td></tr>
</table></td><td>Alesis SamplePad Pro</td></tr>
<tr><td>9 pads 3x3</td><td><table align="center">
<tr><td>7</td><td>8</td><td>9</td></tr>
<tr><td>4</td><td>5</td><td>6</td></tr>
<tr><td>1</td><td>2</td><td>3</td></tr>
</table></td><td>Alesis Strike MultiPad, DDrum NIO, Millenium NonaPad, Roland SPD-S / SPD-SX / SPD-SX PRO</td></tr>
<tr><td>10 pads 2+2x4</td><td><table align="center">
<tr><td>7</td><td>8</td><td>9</td><td>10</td></tr>
<tr><td>3</td><td>4</td><td>5</td><td>6</td></tr>
<tr><td>1</td><td> </td><td> </td><td>2</td></tr>
</table></td><td>Korg MPS-10</td></tr>
<tr><td>12 pads 4x3</td><td><table align="center">
<tr><td>10</td><td>11</td><td>12</td></tr>
<tr><td>7</td><td>8</td><td>9</td></tr>
<tr><td>4</td><td>5</td><td>6</td></tr>
<tr><td>1</td><td>2</td><td>3</td></tr>
</table></td><td>Yamaha DTX-MULTI 12</td></tr>
</table></li>
<li>Press the SEL/OPT knob &#9312; or the YES button  &#9314; to confirm (or press the NO button &#9315; to cancel without changes)</li>
<li>A <a href="#confirmation-pop-ups">confirmation pop-up</a> will show if one of the cells to which you&rsquo;r assigning the multipad triggers is already assigned to another trigger &ndash; press the YES button  &#9314; to confirm or the NO button &#9315; to cancel</li>
</ol>

> [!NOTE]
> Assigning multipad triggers only works if you select a top-left cell which leaves enough space to the right and to the bottom to add all pads.
>
> If one or more of the multipad triggers are already assigned to different cells, they will be removed from their old positions on the trigger matrix.
<br clear=right>

### Setting Up an Input Device

1. Connect the input device to one of the MIDI input ports
2. Go to the [input ports](#12--input-ports) sub-page (1/2) of the [input](#input) page ()
3. [Give the port a recognizable name](#p1-device-name-to-p6-device-name)
4. Set the [MIDI channel](#channel) on which the input device sends note messages (most commonly channel 10 for drums)

> [!TIP]
> Play a trigger/note on the input device when the [MIDI channel](#channel) block is selected to quickly find the right channel and assign it to the port (press the SEL/OPT knob to confirm).
<br clear=right>

### Assigning Triggers to an Input Device

1. Go to the [input notes/pedal cc](#22--input-notespedal-cc) sub-page (2/2) of the [input](#input) page ()
2. Select the [input trigger](#input-trigger) you&rsquo;d like to assign
3. Select the [port/device](#portdevice) you&rsquo;d like to assign it to
4. For each zone/layer you&rsquo;d like to assign:
   1. Select the [note](#note-1-to-n) the input device sends out
   2. *Optionally* select a [pedal CC](#pedal-cc-1-to-n) (continuous controller) number and a [minimum and maximum CC value](#pedal-cc-min-1-to-n--pedal-cc-max-1-to-n) to which the trigger should respond (some electronic drum kits use foot pedal CC &ndash; typically CC number 5 &ndash; to distinguish between open and closed hihat, which both send out the same note)
5. Repeat from step 2 until all triggers are assigned

> [!NOTE]
> An input trigger can be assigned to one input device only.

> [!TIP]
> Play a trigger/note on the input device when a [note](#note-1-to-n) block is selected to quickly find the right note and assign it to the port (press the SEL/OPT knob to confirm). The same can be done with the [pedal cc](#pedal-cc-1-to-n) block.
<br clear=right>

### Setting Up an Output Device

1. Connect the output device to one of the MIDI input ports
2. Go to the [output ports](#13--output-ports) sub-page (1/3) of the [output](#output) page ()
3. [Give the port a recognizable name](#p1-device-name-to-p6-device-name-1)
4. Go to the [output device](#23--output-device) sub-page (2/3) of the [output](#output) page ()
5. *If all the device&rsquo;s voices respond to the same MIDI channel (different note values):* Set the [MIDI channel](#channel) to which the device&rsquo;s voices respond (often channel 10 for drums)
6. *If you&rsquo;re encountering hanging notes:* Try turning off [0 velocity as note off](#0-velocity-as-note-off)
7. *If you&rsquo;re encountering missing notes:* Try disableing [running status](#running-status)
<br clear=right>

### Setting Up an Output Device&rsquo;s Voices

1. Go to the [output voice](#33--output-voice) sub-page (3/3) of the [output](#output) page ()
2. Go to the [voice](#voice) block and either:
   1. *To edit an existing voice:*
      1. Select the voice you would like to edit
      2. Press the SEL/OPT knob and choose &lsquo;rename&rsquo; from the menu to change the name
   2. *To set up a new voice:*
      1. Select &lsquo;[add new]&rsquo;
      2. Press the SEL/OPT knob to give the voice a name
3. *If all the device&rsquo;s voices respond to a different MIDI channel:* Set the [MIDI channel](#channel-1) to which the voice responds
4. *Optionally* set the [note](#note) to which the voice responds &ndash; if not set, you need to [set the note in each program](#note-a-to-d) which uses this voice, otherwise C4 (middle C) is used
5. *Optionally* set [whether and when note off messages are sent](#note-off) &ndash; this can be [overridden in programs](#note-off-a-to-d)
6. *Optionally* set a [velocity threshold](#vel-threshold) and/or a [velocity curve](#velocity-curve)
5. Repeat from step 2 until all voices are ready
<br clear=right>



### Selecting a Bank and a Program

1. Press the PROGRAM button &#9312; to open the program selection pop-up
2. Turn the NAV/&varr; knob &#9313; to switch between program (default) and bank
3. Turn the VAL/&harr; knob &#9314; to select a bank or a program
5. Press the SEL/OPT knob &#9315; or the YES button &#9316; to confirm (or press the NO button &#9317; to cancel)

<br clear=right>

### Setting Up a Program

1. Press the PROGRAM button &ndash; or go to program block on the [program: mapping voices](#program-1) (1/3) or [program: mapping note](#program-2) (2/3) sub-page of the [program](#program) page () &ndash; and either:
   1. *To edit an existing program:* Select the program you would like to edit
   2. *To set up a new program:* Select an empty program (named &lsquo;[empty]&rsquo;)
2. Go to the [program: mapping voices](#13--program-mapping-voices) (1/3) sub-page of the [program](#program) page () and assign output devices and voices to input triggers:
   1. Select the [input trigger](#input-trigger) to which you want to assign an output device and voice
   2. Select the [output port/device](#portdevice--voice-a-to-d) to assign to the trigger
   3. Select a [voice](#portdevice--voice-a-to-d) to assign to the trigger
   4. Go to the [program: mapping note](#23--program-mapping-note) (2/3) sub-page
   5. *Optionally* set the [note](#note-a-to-d) to which the voice responds if you&rsquo;d like to override the [voice&rsquo;s default note setting](#note) and tune the voice to a specific note (if the device&rsquo;s voice supports that)
   6. *Optionally* set [whether and when note off messages are sent](#note-off-a-to-d) &ndash; this overrides the [voice&resquo;s default setting](#note-off)
   7. *Optionally* set [transient curve](#trans-a-to-d), [velocity layer](#lohi-a-to-d) and [velocity scaling](#scale-a-to-d) to create velocity layers or dynamically mix different voices depending on the input velocity
   8. *Optionally* go back to the [program: mapping voices](#13--program-mapping-voices) (1/3) sub-page and repeat from step ii to add multiple device/voice combinations to be triggered at the same time 
3. *Optionally* set [program change](#p1-pc-to-p6-pc) and [bank select](#p1-msb--lsb-to-p6-msb--lsb) messages to be sent to one or more MIDI output ports to choose output devices&rsquo; program for this Cybo-Drummer program
4. [Save the program](#saving-a-program)

#### Assigning Notes to Toms

If you need to assign the same voice to each tom, but tuned differently, the [assign toms](#14--assign-toms) (1/4) sub-page of the [tools](#tools) page () offers a way to quickly do so.

1. Set up at least one tom following the instructions to [set up a program](#setting-up-a-program) (setting a note is not needed)
2. Go to the [assign toms](#14--assign-toms) (1/4) sub-page of the [tools](#tools) page ()
3. Select whether to assign notes to [center or rim](#centerrim)
4. Select [which toms to be included](#tom-1-to-n)
5. Either:
   1. *To assign based on interval:* Select an [interval](#interval) (only which have the same number of notes as the number of included toms can be selected), the [lowest note](#lowest-note) and the [octave](#octave) for the lowest note
   2. *To assign based on chord:* Select a [chord](#chord) (only which have the same number of notes as the number of included toms can be selected), the [lowest note](#lowest-note) and the [octave](#octave) for the lowest note
   3. *To assign a custom series of notes:* [Assign notes to each tom](#tom-1-to-n) separately
6. *Optionally* shift the assigned notes one semitone at a time using the [note up or note down](#note---note-) button, or a full octave using the [octave up or octave down](#oct---oct-) button

> [!NOTE]
> For [interval](#interval) and [chord](#chord) only those options can be selected which have the same number of notes as the number of included toms.
>
> Toms are numbered from high (T1) to low (T*n*), shown on this sub-page as they would be arranged in a typical right-handed setup of a drum kit: from left to right.
>
> The toms assignment tool only runs if [lowest note](#lowest-note) and [octave](#octave) are set and either [interval](#interval) or [chord](#chord), and runs again if one of these is changed.
>
> The parameters set on the [assign toms](#14--assign-toms) (1/4) sub-page ([interval](#interval), [chord](#chord), [lowest note](#lowest-note), [octave](#octave) and [included toms](#tom-1-to-n)) are not stored in the program. These settings are derived from the program&rsquo;s mapping data each time the tools page loads, by looking for the first combination of parameters (for both interval and chord) which fits. Manually changing the notes might or might not give a match.
>
> If more than one tom has output device(s) and voice(s) assigned, Cybo-Drummer will look for the group of toms with the most definitions in common, starting from the lowest tom (highest T number in the trigger matrix), and assume that those are the included toms.

#### Assigning Single Notes to Multipad Triggers

If you need to assign the same voice to multiple pads of a multipad trigger device, the [multipad: select mode](#24--multipad-select-mode) (2/4) and [multipad: assign notes](#34--multipad-assign-notes) (3/4) sub-pages of the [tools](#tools) page () offer a way to quickly do so. This can be used to easily set up multipad devices for pitched percussion or melodic instruments, playing single notes (as described here) or [chords](#assigning-chords-to-multipad-triggers).

1. Set up the trigger layer you want to assign for at least one pad of the multipad following the instructions to [set up a program](#setting-up-a-program) (setting a note is not needed) &ndash; if you want to assign the notes only to one velocity layer, you should set up that velocity layer in the program definition
2. Go to the [multipad: select mode](#24--multipad-select-mode) (2/4) sub-page of the [tools](#tools) page ()
3. Select the [multipad trigger layer](#multipad-layer) (layer A, layer B, layer C or layer D) to the one you would like to assign
4. Either:
   1. *To assign all pads:* Press the [all to note](#all-to-note) button to set all pads to notes
   2. *To assign some of the pads:* For each pad to be included [set its mode](#pad-1-to-n) to &lsquo;note&rsquo;
5. Go to the [multipad: assign notes](#34--multipad-assign-notes) (3/4) sub-page of the [tools](#tools) page ()
6. Select which [velocity layer](#lohi) you&rsquo;d like to assign (select &lsquo;all&rsquo; to not ignore velocity layers)
7. Either:
   1. *To assign based on scale or mode:*
      1. Select assignment [pattern](#pattern) (first up and then left or first left and then right)
      2. Select a [scale or mode](#scalemode), a [key](#key) and an [octave](#octave-1)
      3. *Optionally* select how much the [shift](#shift) the root note (tonic) assignment left/down or right/up
   2. *To assign a custom series of notes:* [Assign notes to each pad](#pad-1-to-n-1) separately

> [!NOTE]
> The multipad note assignment tool only runs if [key](#key) and [octave](#octave-1) and runs again if one of these is changed.
>
> The parameters set on the [multipad: assign notes](#34--multipad-assign-notes) (3/4) sub-page ([scale/mode](#scalemode), [pattern](#pattern), [key](#key), [octave](#octave-1) and [shift](#shift)) are not stored in the program. These settings are derived from the program&rsquo;s mapping data each time the tools page loads, by looking for the first combination of parameters (for both interval and chord) which fits. If the same combination of notes might be interpreted in more than one way, it will take the first one it encounters. Manually changing the notes might or might not give a match.
>
> If more than one pad has output device(s) and voice(s) assigned, Cybo-Drummer will look for the group of pads with at max one note assigned and the most definitions in common, starting from the first pad (bottom left), and assume that those are the included pads.
>
> Setting the [velocity layer (hi/lo)](#lohi) to &lsquo;all&rsquo; affects all program layers, independently to what velocity layer it&rsquo;s set to (all, high, low). If [velocity layer (hi/lo)](#lohi) is set to &lsquo;high&rsquo; or &lsquo;low&rsquo;, only the program layers (A to D &ndash; assigned on [program: mapping voices](#13--program-mapping-voices) and [program: mapping note](#23--program-mapping-note)) assigned to that velocity layer in the identified reference pad will be copied to all other pads, removeing program layers set to the same velocity layer, but not those set to a different one.
<br clear=right>

#### Assigning Chords to Multipad Triggers

If you need to assign the same voice to multiple pads of a multipad trigger device, the [multipad: select mode](#24--multipad-select-mode) (2/4) and [multipad: assign chords](#44--multipad-assign-chords) (4/4) sub-pages of the [tools](#tools) page () offer a way to quickly do so. This can be used to easily set up multipad devices for pitched percussion or melodic instruments, playing single [notes](#assigning-single-notes-to-multipad-triggers) or chords (as described here).

1. Set up the trigger layer you want to assign for at least one pad of the multipad following the instructions to [set up a program](#setting-up-a-program) (setting a note is not needed, but if you need to distinguish between pads assigned to single notes and pads assigned to chords, set at least two identical layers with different notes to make Cybo-Drummer recognize it as a chord)
2. Go to the [multipad: select mode](#24--multipad-select-mode) (2/4) sub-page of the [tools](#tools) page ()
3. Select the [multipad trigger layer](#multipad-layer) (layer A, layer B, layer C or layer D) to the one you would like to assign
4. Either:
   1. *To assign all pads:* Press the [all to chord](#all-to-chord) button to set all pads to notes
   2. *To assign some of the pads:* For each pad to be included [set its mode](#pad-1-to-n) to &lsquo;chord&rsquo;
5. Go to the [multipad: assign chords](#34--multipad-assign-chords) (3/4) sub-page of the [tools](#tools) page ()
6. One by one [assign chords to each pad](#pad-1-to-n-2)
7. *Optionally* shift the assigned chords one semitone at a time using the [note up or note down](#note---note--1) button, or a full octave using the [octave up or octave down](#octave---octave-) button

> [!NOTE]
> Chord definitions (root, octave, chord quality and inversion) are not stored in the program. The type of chord is derived from the notes which are stored each time the tools page loads, by looking for the first combination of settings which fits. If the same combination of notes might be interpreted in more than one way, it will take the first one it encounters.
>
> If more than one pad has output device(s) and voice(s) assigned, Cybo-Drummer will look for the group of pads with more than program layer which are identical except for the assigned note, starting from the first pad (bottom left), and assume that those are the included pads. The chord assignment tool takes program layer A of that pad as source.
<br clear=right>



### Saving a Program

*When the active program has unsaved changes (indicated by an asterisk behind the program number in the top-left corner of the screen):*

1. Press the PROGRAM button &#9312; to open a pop-up to select where you&rsquo;d like to save the program (jump straight to step 5 to just save the active program)
2. Turn the NAV/&varr; knob &#9313; to switch between program (default) and bank
3. Turn the VAL/&harr; knob &#9314; to select a bank or a program
5. Press the SEL/OPT knob &#9315; or the YES button &#9316; to confirm (or press the NO button &#9317; to cancel)
6. You&rsquo;re finished if you&rsquo;re saving an existing program without changing the bank/program combination, otherwise either:
   * *If you&rsquo;re saving a new program or you selected an unused bank/program combination:* A [text edit pop-up](#text-edit-pop-up) will show to give the program a name
   * *If you select an existing program:* [Confirm](#confirmation-pop-ups) that you want to replace it

> [!NOTE]
> If you change the program (via the program block on [program: mapping voices](#13--program-mapping-voices), [program: mapping note](#23--program-mapping-note) or [program: pc/bank select](#33--pcbank-select) or via MIDI) when the active program has unsaved changes, you will be asked if you want to save changes, and if you [confirm](#confirmation-pop-ups) you start the same procedure as described above.
<br clear=right>



### Selecting a Trigger

1. Long-press the TRIGGER button &#9312; to show a trigger preset selection pop-up
2. Turn the VAL/&harr; knob &#9313; to select an output trigger preset
3. Press the YES button &#9314; to confirm or the NO button &#9315; to cancel

> [!TIP]
> Short-press the TRIGGER button to trigger the last selected output trigger preset (for testing purposes).

<br clear=right>



### Confirmation Pop-Ups

Cybo-Drummer doesn&rsquo;t have an undo feature, so to avoid accidentally losing data confirmation pop-ups will show up before deleting something, changing an unsaved program, replacing a program, restoring a back-up or doing a factory reset.

* Press the YES button &#9312; to confirm
* Press the NO button &#9313; to cancel
<br clear=right>



### Text edit pop-up

When renaming a program, device, trigger or setting a text edit pop-up is shown. It shows the text and a selection of characters plus a space bar.

* Turn the NAV/&varr; knob &#9312; to change navigate by row and the VAL/&harr; knob &#9313; to navigate by column and press the SEL/OPT &#9314; knob to add a character
* Press the DEL knob &#9315; to remove the last character (backspace)
* Press the YES button &#9316; to confirm the changes
* Press the NO button &#9317; to cancel renaming
<br clear=right>

## Description of All Pages and Sub-Pages

### &emsp;Program

Use the program page to [edit programs](#setting-up-a-program), which are the part of the mapping routes which change with the [selected program](#selecting-a-bank-and-a-program).

The [program: mapping voices](#13--program-mapping-voices) (1/3) sub-page is the default view when powering up Cybo-Drummer.
<br clear=right>

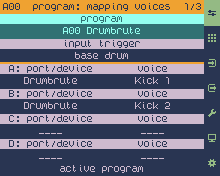
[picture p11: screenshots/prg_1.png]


#### &ensp;1/3 &ndash; program: mapping voices

##### program

* Turn the VAL/&harr; knob to **select the active program** (0 to 99) within the active bank ([use the TRIGGER button](#selecting-a-trigger) instead to change the bank), then press the knob to confirm
* Press the SEL/OPT knob &#9312; to show an **options menu**, then turn the VAL/&harr; knob &#9313; to select an option and press the SEL/OPT knob &#9312; or the YES button &#9314; to confirm (or press the NO button &#9315; to cancel) &ndash; menu options:
  * ***rename:*** show a [text edit pop-up](#text-edit-pop-up) to rename the active program
  * ***move backward:*** move the active program one place backward (if not the first program)
  * ***move forward:*** move the active program one place forward (if not the last program)
  * ***move to…:*** move the active program to a specific position &ndash; shows a pop-up to select the bank and program position (turn the NAV/&varr; knob to select bank or program, turn the VAL/&harr; knob to select a number and press the SEL/OPT knob or the YES button to confirm or the NO button to cancel) &ndash; if you select a non-blank program, that program and all subsequent programs until the first blank slot will be shifted one position up (moving will fail if no free spot is left in the selected bank)
* Press the DEL knob to:
  * **delete the active program** if a non-empty program is selected (a [confirmation pop-up](#confirmation-pop-ups) will show)
  * **remove an empty program position** if an empty program is selected, shifting all subsequent programs in the active bank one position down (a [confirmation pop-up](#confirmation-pop-ups) will show)
 
> [!TIP]
> Programs can also be changed from any page/sub-page by [pressing the PROGRAM button](#selecting-a-bank-and-a-program). That is also the way to change the bank.

##### input trigger

* Select the active input trigger to map one up to four output device/voice combinations to (four program layers)

> [!TIP]
> The active input trigger can also be selected by [long-pressing the TRIGGER button](#selecting-a-trigger)
<!--TO DO: double check MIDI learn logic and probably change the way trigger setting works-->
<!--\> If [MIDI learn](#midi-learn) is turned on input device and input preset can also be set to an already mapped device/preset by selecting the respective block and playing the trigger/note on your input device (please note that this is an exception where MIDI learn is not listening to the set MIDI learn port).-->

##### port/device / voice A to D

<i>Applies to the active [program](#program-1) and selected [input trigger](#input-trigger)</i>

* Turn the VAL/&harr; knob to **map up to 4 output ports/devices and voice combinations** (program layers A, B, C and D) &ndash; these voices will be triggered when the router receives the selected input trigger
* Press the DEL knob on a port/device block to **clear the port/device and voice assignment**

> [!IMPORTANT]
> First select an output port/device, then a voice &ndash; the mapping will only be stored (into the unsaved program) after both a port/device and a voice have been assigned. Changing the output port/device clears the voice selection.
>
> Port/device and program layers A to D change the output mapping for the above selected [input trigger](#input-trigger). To map an input trigger to an output voice, first select the input trigger and then assign the output ports/devices and voices.

> [!TIP]
> Multiple output devices can be combined such that one input trigger triggers multiple output devices&rsquo; voices &ndash; either at the same time, or [dependent on the input trigger velocity](#trans-a-to-d).
<br clear=right>

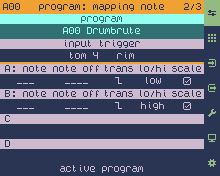
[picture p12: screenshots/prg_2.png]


#### &ensp;2/3 &ndash; program: mapping note

##### program

* Turn the VAL/&harr; knob to **select the active program** (0 to 99) within the active bank ([use the TRIGGER button](#selecting-a-trigger) instead to change the bank), then press the knob to confirm
* Press the SEL/OPT knob to show an **options menu**, then turn the VAL/&harr; knob to select an option and press the SEL/OPT knob or the YES button to execute (or press the NO button to leave the options menu) &ndash; see [program](program) on [program: mapping voices](#13--program-mapping-voices) (1/3) sub-page for a description of the menu
* Press the DEL knob to **delete the active program** &ndash; (a [confirmation pop-up](#confirmation-pop-ups) will show)
 
> [!TIP]
> Programs can also be changed from any page/sub-page by [pressing the PROGRAM button](#selecting-a-bank-and-a-program). That is also the way to change the bank.

##### input trigger

* Select the active input trigger to map one up to four output device/voice combinations to (four program layers)

> [!TIP]
> The active input trigger can also be selected by [long-pressing the TRIGGER button](#selecting-a-trigger)
<!--TO DO: double check MIDI learn logic and probably change the way trigger setting works-->
<!--\> If [MIDI learn](#midi-learn) is turned on input device and input preset can also be set to an already mapped device/preset by selecting the respective block and playing the trigger/note on your input device (please note that this is an exception where MIDI learn is not listening to the set MIDI learn port).-->

##### note A to D

<i>Applies to the active [program](#program-2) and selected [input trigger](#input-trigger-1)</i>

* *Optional*&ensp;Turn the VAL/&harr; knob to **set program layer&rsquo;s note** (C-1 to G9), overriding the device&rsquo;s [voice note setting](#note)
* Press the DEL knob to **clear the note setting** (set to &lsquo;___&rsquo;)
* Clear / set to &lsquo;___&rsquo; to use the [voice&rsquo;s default note](#note)

> [!TIP]
> Output notes can be set here in the program or [in the voice settings](#note). Use the voice note setting to set the default note for that voice (or the only one it responds to, if that&rsquo;s the case). Use the program note settings to override the default and tune the voice to a specific note (if the device&rsquo;s voice supports that) &ndash; different triggers can be assigned to the same voice with a different note.
>
> The [tools](#tools) page () offers a quick way to assign the same voice tuned differently to [toms](#assigning-notes-to-toms) or multipad triggers ([single notes](#assigning-single-notes-to-multipad-triggers), for example to play pitched percussion, or [chords](#assigning-chords-to-multipad-triggers)). C4 (middle C) is used if neither the voice setting, nor the program setting specifies a note.
>
> If a device doesn&rsquo;t respond to the notes your assigned as expected, try one octave lower or one octave higher. There is no official MIDI standard for octave numbers. Cybo-Drummer follows the Scientific Pitch Notation standard, which defines the middle C as C4, so in Cybo-Drummer MIDI note 60 is C4, but some manufacturers define MIDI note as C3 and some as C5.
>
> If [MIDI learn](#midi-learn) is turned on note can also be set by paying a note from a device connected to the set [MIDI learn port](#midi-learn-port).

##### note off A to D

<i>Applies to the active [program](#program-2) and selected [input trigger](#input-trigger-1)</i>

* *Optional*&ensp;Turn the VAL/&harr; knob to **set whether and when to send note off messages**, overriding the [voice-level note off setting](#note-off):
  * *____:*&ensp;use the [voice&rsquo;s default setting]([#note-off)
  * *off:*&ensp;disable sending note off messages (default)
  * *pulse:*&ensp;send a note off message immediately after sending a note on message
  * *toggle:*&ensp;send a note off message if triggered again (first trigger received sends a note on message, second trigger a note off message)
  * *80 ms* to *1000 ms:*&ensp;send a note off message with a delay of 80 to 1000 milliseconds
* Press the DEL knob to **clear the note off setting** (set to &lsquo;___&rsquo;)
* Clear / set to &lsquo;___&rsquo; to use the [voice&rsquo;s default note off setting](#note-off)

> [!NOTE]
> The MIDI specification prescribes to always send note off messages, however most drum computers ignore them, so it is more efficiently not to send them. Turn on if you experience problems or for example if you&rsquo;re triggering a synth pad instead of a percussive sound.

> [!TIP]
> Note off settings can be set here in the program or [in the voice settings](#note-off). Program note setting overrides voice note off setting.

##### trans A to D

<div align="center">

</div>

<i>Four different <a href="#trans-a-to-d">transient curve options</a> and what the relation between <a href="#lohi-a-to-d">the low velocity layer and the high velocity layer</a> looks like if both velocity layers are set to the same curve</i>

<i>Applies to the active [program](#program-2) and selected [input trigger](#input-trigger-1)</i>

* *Optional*&ensp;Turn the VAL/&harr; knob to **set a transient curve** to make the [low or high end of the input trigger velocity](#lohi-a-to-d) trigger a program layer stronger:
  * *__:*&ensp;off &ndash; the full input velocity is mapped to the output velocity
  * * (hard):*&ensp;hard split the input velocity into two halves and only trigger the selected [velocity layer](#lohi-a-to-d) for half of the input velocity 
  * * (smooth 1):*&ensp;split the input velocity into two halves, but smoothly decrease the amount of triggering the selected [velocity layer](#lohi-a-to-d) in a narrow range in the middle
  * * (smooth 2):*&ensp;split the input velocity into two halves, but smoothly decrease the amount of triggering the selected [velocity layer](#lohi-a-to-d) in a wide range in the middle
  * * (linear):*&ensp;gradually decrease the triggering of the selected [velocity layer](#lohi-a-to-d) over the full trigger velocity range
* Press the DEL knob to **disable the layer&rsquo;s transient curve** (set to &lsquo;__&rsquo;)

> [!TIP]
> Transient curves and [velocity layers](#lohi-a-to-d) can be used to play two different voices with one input trigger, depending on whether you play soft or hard &ndash; this works best with hard transients. It can also be used to create dynamic effects (in many variations) where a voice becomes more prominent or gets mixed in when you play softly or when you play firmly.

##### lo/hi A to D

<i>Applies to the active [program](#program-2) and selected [input trigger](#input-trigger-1)</i>

* Turn the VAL/&harr; knob to **set to which end of the volocity range a program layer should repond**:
  * *low:*&ensp;respond to the lower end of the input trigger&rsquo;s velocity range (depending on the selected [transient curve](#trans-a-to-d))
  * *high:*&ensp;respond to the higher end of the input trigger&rsquo;s velocity range (depending on the selected [transient curve](#trans-a-to-d))
* This option is not available if a program layer&rsquo;s [transient curve](#trans-a-to-d) is set to &lsquo;__&rsquo; (off)

##### scale A to D

<div align="center">

</div>

<i>Illustration of the impact of turning <a href="#scale-a-to-d">scale</a> on or off on the four different <a href="#trans-a-to-d">transient curve options</a> looks like if both <a href="#lohi-a-to-d">velocity layers</a> are set to the same curve (and the voice&rsquo;s <a href="#velocity-curve">velocity curves</a> are set to linear)</i>

<i>Applies to the active [program](#program-2) and selected [input trigger](#input-trigger-1)</i>

* Turn the VAL/&harr; knob or press the SEL/OPT knob to **switch between scaling () and not scalling () a program layer&rsquo;s output velocity to the full velocity range** (0 to 127)
* Press the DEL knob to **enable scaling ()** (default setting)
* This option is not available if a program layer&rsquo;s [transient curve](#trans-a-to-d) is set to &lsquo;__&rsquo; (off)
<br clear=right>

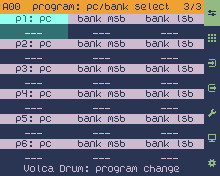
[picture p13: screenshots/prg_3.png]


#### &ensp;3/3 &ndash; pc/bank select

##### p1: pc to p6: pc

<i>Applies to the active [program](#program-1)</i>

* *Optional*&ensp;Turn the VAL/&harr; knob to **set a program change value** (0 to 127), which will be sent to the device assigned to a particular [output port](#p1-device-name-to-p6-device-name-1) on router program change (after sending [bank select](#p1-msb--lsb-to-p6-msb--lsb), if set)
* Press the DEL knob to **clear the program change setting** (set to &lsquo;___&rsquo;)
* Clear / set to &lsquo;___&rsquo; to not send a program change message

> [!NOTE]
> Some MIDI devices number programs 0 to 127, some number them 1 to 128 &ndash; in the latter case you need to set a one position lower program change value on Cybo-Drummer, compared to the output device&rsquo;s number.

##### p1: msb / lsb to p6: msb / lsb

<i>Applies to the active [program](#program-1)</i>

* *Optional*&ensp;Turn the VAL/&harr; knob to **set most significant byte (msb) bank select value** (0 to 127) and **least significant byte (msb) bank select value** (0 to 127), which will be sent to the device assigned to a particular [output port](#p1-device-name-to-p6-device-name-1) on router program change (before sending [program change](#p1-pc-to-p6-pc), if set)
* Press the DEL knob to **clear bank select msb or lsb setting** (set to &lsquo;___&rsquo;)
* Clear / set to &lsquo;___&rsquo; to not send a bank select msb or lsb message &ndash; it is possible to only send an msb or only an lsb value

> [!NOTE]
> Cybo-Drummer uses raw 0 to 127 MSB and LSB values for bank select, because MIDI devices implement bank select in many different ways, including in cases using only one of the two MIDI CC (continuous controller) messages. Refer to your device&rsquo;s manual and MIDI specifications for details on how to set bank select (and if it is used). If bank select is used to set a single number in the range 0 to 16,383 or 1 to 16,384, that number would typically be calculated as MSB × 128 + LSB or MSB × 128 + LSB + 1.
<br clear=right>

### &emsp;Trigger Matrix

Use the trigger matrix page to [organize input triggers on the trigger matrix](#organizing-input-triggers-on-the-trigger-matrix).
<br clear=right>



#### &ensp;1/4 &ndash; program & trigger matrix

This sub-page shows the active program and allows you to edit the trigger matrix visualizing the [saved input trigger setup](#setting-up-an-input-device) on an 8×8 grid.

> [!NOTE]
> The trigger matrix is a global setting and is not stored and recalled with program (all programs use the same trigger matrix configuration)

##### *Matrix Cell 1 to 64*

* Short press the SEL/OPT knob to show a **[trigger selection pop-up](#organizing-input-triggers-on-the-trigger-matrix)**
* Long press the SEL/OPT knob to [**add all triggers of a multipad device at once**](#adding-all-triggers-of-a-multipad-device-at-once)
* Press DEL knob to **clear the cell&rsquo;s assignment** (a [confirmation pop-up](#confirmation-pop-ups) will show)

> [!NOTE]
> If you assign a trigger which is already assigned to a different cell, it will be removed from its old position on the trigger matrix, so you&rsquo;re essentially moving it to a new location.

<!--TO BE ADDED: Trigger matrix supports MIDI learn (watch out!)-->

<br clear=right>

### &emsp;Input

Use the input page to name input ports to the connected devices and to adjust input device settings.
<br clear=right>

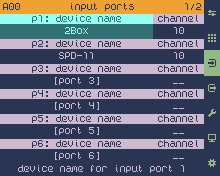
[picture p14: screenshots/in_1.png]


#### &ensp;1/2 &ndash; input ports

##### p1: device name to p6: device name

* Press the SEL/OPT knob to open a [text edit pop-up](#text-edit-pop-up) to **name the input MIDI port** such that it represents the connected device
* Press the DEL knob to clear the port/device name (a [confirmation pop-up](#confirmation-pop-ups) will show)

##### p1: channel to p1: channel

* Turn the VAL/&harr; knob to **set the input port/device&rsquo;s MIDI channel** (1 to 16)
* Press the DEL knob to **clear channel setting** (set to &lsquo;__&rsquo;)

> [!NOTE]
> Cybo-Drummer requires an input channel to be set to work. The port will only listen to MIDI messages on that channel. If no channel is set the port will not respond to any MIDI messages.
>
> Some MIDI devices number MIDI channels 1 to 16, some number them 0 to 15 &ndash; in the latter case you need to set a one position higher channel value on Cybo-Drummer, compared to the input device&rsquo;s number. 

> [!TIP]
> If [MIDI learn](#midi-learn) is turned on channel can also be set by sending anything from that channel from a device connected to the set [MIDI learn port](#midi-learn-port).
<br clear=right>

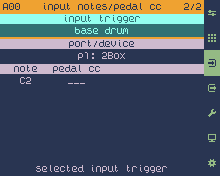
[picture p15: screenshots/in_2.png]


#### &ensp;2/2 &ndash; input notes/pedal cc

##### input trigger

* Turn the VAL/&harr; knob to **select the trigger to edit**
* The trigger can also be selected by long-pressing the TRIGGER button, which opens the [trigger selection pop-up](#selecting-a-trigger)

##### port/device

* Turn the VAL/&harr; knob to **set the input port/device** (p1 to p6) assigned to the selected input trigger

> [!TIP]
> The input port/device can also be set by playing a trigger/note on your input device (this is an exception where MIDI learn is not listening to the set MIDI learn port).

##### note 1 to *n*

<i>Applies to the selected [input trigger/zone](#input-trigger-2) &ndash; the number of zones/layers [depends on the input trigger](#triggers-and-zoneslayers)</i>

* Turn the VAL/&harr; knob to **select a zone/layer&rsquo;s note** (C-1 to G9)

> [!TIP]
> If a device doesn&rsquo;t respond to the notes your assigned as expected, try one octave lower or one octave higher. There is no official MIDI standard for octave numbers. Cybo-Drummer follows the Scientific Pitch Notation standard, which defines the middle C as C4, so in Cybo-Drummer MIDI note 60 is C4, but some manufacturers define MIDI note as C3 and some as C5.
>
> The note can also be set by playing a trigger/note on your input device (this is an exception where MIDI learn is not listening to the set MIDI learn port).

##### pedal cc 1 to *n*

<i>Applies to the selected [input trigger/zone](#input-trigger-2) &ndash; the number of zones/layers [depends on the input trigger](#triggers-and-zoneslayers)</i>

* *Optional*&ensp;Turn the VAL/&harr; knob to **set a zone/layer&rsquo;s CC** (continuous controller) **number** (1 to 128) **on which triggering should be [dependent](#pedal-cc-min-1-to-n--pedal-cc-max-1-to-n)**
* Press the DEL knob to **clear pedal CC setting** (set to &lsquo;___&rsquo;)
* Some electronic drum kits use foot pedal CC &ndash; typically CC number 5 &ndash; to distinguish between open and closed hihat, which both send out the same note
* Set pedal CC to &lsquo;__&rsquo; if not relevant for the selected trigger

> [!TIP]
> The pedal CC number can also be set by playing a trigger/note on your input device (this is an exception where MIDI learn is not listening to the set MIDI learn port).

##### pedal cc min 1 to *n* / pedal cc max 1 to *n*

<i>Applies to the selected [input trigger/zone](#input-trigger-2) &ndash; the number of zones/layers [depends on the input trigger](#triggers-and-zoneslayers)</i>

* *Optional*&ensp;urn the VAL/&harr; knob to **set a minimum and maximum [pedal CC](#pedal-cc)** (continuous controller) **value** (0 to 127) between which to trigger a zone/layer
* Some electronic drum kits use foot pedal CC &ndash; typically CC number 5 &ndash; to distinguish between open and closed hihat, which both send out the same note
* Press the DEL knob to **minimum pedal CC value to 0** (lowest possible value) or **maximum pedal CC value to 127** (highest possible value)

> [!TIP]
> Pedal CC minimum or maximum can also be set by sending CC messages (which CC number doesn&rsquo;t matter) from your input device (this is an exception where MIDI learn is not listening to the set MIDI learn port).
<br clear=right>

### &emsp;Output

Use the output page to name output ports to the connected devices, to adjust output device settings and to define output device&rsquo;s voices.
<br clear=right>

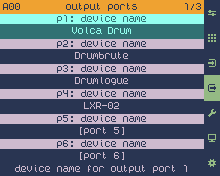
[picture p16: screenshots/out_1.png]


#### &ensp;1/3 &ndash; output ports

##### p1: device name to p6: device name

* Press the SEL/OPT knob to open a [text edit pop-up](#text-edit-pop-up) to **name the output MIDI port** such that it represents the connected device
* Press the DEL knob to clear the port/device name (a [confirmation pop-up](#confirmation-pop-ups) will show)
<br clear=right>

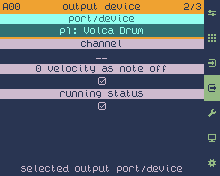
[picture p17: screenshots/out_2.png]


#### &ensp;2/3 &ndash; output device

##### port/device

* Turn the VAL/&harr; knob to **set the output port/device** (p1 to p6) to edit

> [!NOTE]
> Selecting a port/device on this page changes the selected [port/device](#portdevice-2) on the [output voice](#33--output-voice) (3/3) sub-page as well.

<!--TO DO: double check MIDI learn-->

##### channel

<i>Applies to the selected [output port/device](#portdevice-1)</i>

* *Optional*&ensp;Turn the VAL/&harr; knob to **set the input port/device&rsquo;s MIDI channel** (1 to 16)
* Press the DEL knob to **clear channel setting** (set to &lsquo;__&rsquo;)

> [!IMPORTANT]
> This MIDI channel is used to send control data (program change, bank select), which is not overridden by the [voice-level channel](#channel-1).

> [!TIP]
> Output MIDI channel can be set here at device level or at [voice level](#channel-1). Set the device-level channel setting if all a device&rsquo;s voice use the same MIDI channel (typically assigned to different notes on the same channel). Set the voice-level channel setting if each voice uses a different MIDI channel. Voice-level channel overrides device-level channel. Channel 10 is used if neither device-level nor voice-level channel is set.

##### 0 velocity as note off

<i>Applies to the selected [output port/device](#portdevice-1)</i>

* Turn the VAL/&harr; knob or press the SEL/OPT knob to **switch between sending note on messages with velocity 0 ()** instead of note off messages **and to force the use of note off messages ()**
* Press the DEL knob to **turn on velociy as note off ()** (default setting)

>[!NOTE]
> 0 velocity as note off requires less MIDI data if combined with [running status](#running-status). To be fully compliant to the MIDI specification a device should recognize note on messages with 0 velocity as note off, so by far most devices do support this &ndash; only turn it off if you experience problems.

##### running status

<i>Applies to the selected [output port/device](#portdevice-1)</i>

* Turn the VAL/&harr; knob or press the SEL/OPT knob to **switch between enabling running status () and disabling it ()**
* Press the DEL knob to **enable running status ()** (default setting)

>[!NOTE]
> Running status is a way to maximize MIDI data efficiency by leaving out the status byte if consecutive MIDI messages share the same status byte. This leads to even more efficiency if combined with sending [note on messages with 0 velocity instead of note off messages](#0-velocity-as-note-off). To be fully compliant to the MIDI specification a device should recognize running status, so by far most devices do support this &ndash; only turn it off if you experience problems.
<br clear=right>

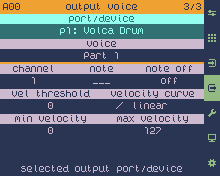
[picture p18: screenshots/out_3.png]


#### &ensp;3/3 &ndash; output voice

##### port/device

* Turn the VAL/&harr; knob to **set the output port/device** (p1 to p6) to edit

> [!NOTE]
> Selecting a port/device on this page changes the selected [port/device](#portdevice-1) on the [output device](#23--output-device) (2/3) sub-page as well.
<!--TO DO: double check MIDI learn-->
<br clear=right>



##### voice

* Turn the VAL/&harr; knob to **set the output port/device&rsquo;s voice** to edit
* *If an existing voice is selected:* Press the SEL/OPT knob &#9312; to show an **options menu**, then turn the VAL/&harr; knob &#9313; to select an option and press the SEL/OPT knob &#9312; or the YES button &#9314; to execute (or press the NO button &#9315; to leave the options menu) &ndash; menu options:
  * ***rename:*** show a [text edit pop-up](#text-edit-pop-up) to rename the selected voice
  * ***move backward:*** move the selected voice one place backward (if not the first voice)
  * ***move forward:*** move the selected voice one place forward (if not the last voice)
  * ***move to…:*** move the selected voice to a specific position &ndash; shows a pop-up to select the position (turn the VAL/&harr; knob to select a number and press the SEL/OPT knob or the YES button to confirm or the NO button to cancel) all voices after the selected position will be shifted one position up
* *If a new voice (&lsquo;[add new]&rsquo;) is selected:* Press the SEL/OPT knob to show a [text edit pop-up](#text-edit-pop-up) to **rename the selected voice**
* Press the DEL knob to **delete the voice**
* Select &lsquo;[add new]&rsquo; (the value after the last existing voice) to add a new voice

> [!NOTE]
> Renaming a voice can take some time to process, because it needs to make adjustments to each program, which are saved in sepparate files. Wait for the pop-up showing &lsquo;processing&hellip;&rsquo; to disappear.

##### channel

<i>Applies to the selected [output port/device](#portdevice-2) and [voice](#voice)</i>

* *Optional*&ensp;Turn the VAL/&harr; knob to **set the voice&rsquo;s MIDI channel** (1 to 16)
* Press the DEL knob to **clear channel setting** (set to &lsquo;__&rsquo;)

> [!IMPORTANT]
> The [device-level MIDI channel](#channel) is used to send control data (program change, bank select), which is not overridden by this voice-level channel.

> [!TIP]
> Output MIDI channel can be set at [device level](#channel) or here at voice level. Set the device-level channel setting if all a device&rsquo;s voices use the same MIDI channel (typically assigned to different notes on the same channel). Set the voice-level channel setting if each voice uses a different MIDI channel. Trigger-level channel overrides device-level channel. Channel 10 is used if neither device-level nor voice-level channel is set.
> 
> If [MIDI learn](#midi-learn) is turned on channel can also be set by sending anything from that channel from a device connected to the set [MIDI learn port](#midi-learn-port).

##### note

<i>Applies to the selected [output port/device](#portdevice-2) and [voice](#voice)</i>

* *Optional*&ensp;Turn the VAL/&harr; knob to **set a voice&rsquo;s note** (C-1 to G9)
* Press the DEL knob to **clear the note setting** (set to &lsquo;___&rsquo;)

> [!TIP]
> Output notes can be set [in the program](#note-a-to-d) or here in the voice settings. Use the voice note setting to set the default note for that voice (or the only one it responds to, if that&rsquo;s the case). Use the program note settings to override the default and tune the voice to a specific note (if the device&rsquo;s voice supports that) &ndash; different triggers can be assigned to the same voice with a different note.
>
> The [tools](#tools) page () offers tools to quickly assign the same voice tuned differently to [toms](#assigning-notes-to-toms) or multipad triggers ([single notes](#assigning-single-notes-to-multipad-triggers), for example to play pitched percussion, or [chords](#assigning-chords-to-multipad-triggers)). C4 (middle C) is used if neither the voice setting, nor the program setting specifies a note.
>
> If a device doesn&rsquo;t respond to the notes your assigned as expected, try one octave lower or one octave higher. There is no official MIDI standard for octave numbers. Cybo-Drummer follows the Scientific Pitch Notation standard, which defines the middle C as C4, so in Cybo-Drummer MIDI note 60 is C4, but some manufacturers define MIDI note as C3 and some as C5.
>
> If [MIDI learn](#midi-learn) is turned on note can also be set by paying a note from a device connected to the set [MIDI learn port](#midi-learn-port).

##### note off

<i>Applies to the selected [output port/device](#portdevice-2) and [voice](#voice)</i>

* *Optional*&ensp;Turn the VAL/&harr; knob to **set whether and when to send note off messages**:
  * *off:*&ensp;disable sending note off messages (default)
  * *pulse:*&ensp;send a note off message immediately after sending a note on message
  * *toggle:*&ensp;send a note off message if triggered again (first trigger received sends a note on message, second trigger a note off message)
  * *80 ms* to *1000 ms:*&ensp;send a note off message with a delay of 80 to 1000 milliseconds
* Press the DEL knob to **set note off to &lsquo;off&rsquo;**

> [!NOTE]
> The MIDI specification prescribes to always send note off messages, however most drum computers ignore them, so it is more efficiently not to send them. Turn on if you experience problems or for example if you&rsquo;re triggering a synth pad instead of a percussive sound.

> [!TIP]
> Note off settings can be set [in the program](#note-off-a-to-d) or here in the voice settings. Program note setting overrides voice note off setting.

##### vel threshold

<div align="center">

</div>

<i>Example of what the velocity curves look like if the threshold is set to 20</i>

<i>Applies to the selected [output port/device](#portdevice-2) and [voice](#voice)</i>

* Turn the VAL/&harr; knob to **set a velocity level** (0 to 127) **under which trigger input is ignored**
* Press the DEL knob to **set the velocity threshold to 0**
* Set the threshold to 0 for no threshold

> [!NOTE]
> The velocity threshold is independent of the [velocity curve](#velocity-curve) setting: it cuts it off without scaling (see charts above).

> [!TIP]
> Velocity threshold can be used to avoid loud double triggers on a drum computer with just one or two velocity levels when (accidentally) playing soft ghost notes.

##### velocity curve

<div align="center">

</div>

<i>Charts showing each velocity response curve option</i>

<i>Applies to the selected [output port/device](#portdevice-2) and [voice](#voice)</i>

* Turn the VAL/&harr; knob to **adjust the velocity response dynamics** in three increasingly positive steps (&lsquo;positive 1&rsquo;, &lsquo;positive 2&rsquo;, &lsquo;positive 3&rsquo;), three increasingly negative steps (&lsquo;negative 1&rsquo;, &lsquo;negative 2&rsquo;, &lsquo;negative 3&rsquo;) or select &lsquo;linear&rsquo; (the default) not to change the velocity (velocity out level = velocity in level)
* Press the DEL knob to **set the velocity curve to linear**
* Positive curves make the output velocity louder (like a compressor), negative curves make it weaker

> [!TIP]
> For drum computers with just two velocity levels, you can adjust the threshold between the first and second level by adjusting the curve: a positive curve makes the second level come in earlier (at a lower input velocity), a negative curve makes it come in later (at a higher input velocity).

> [!IMPORTANT]
> MIDI velocity only has a resolution of 127 steps (1 to 127 &ndash; 0 is note off). Adjusting the velocity curve significantly reduces that resolution:
>
> * *positive 1 / negative 1:* from 127 to 95 steps
> * *positive 2 / negative 2:* from 127 to 64 steps
> * *positive 3 / negative 3:* from 127 to 32 steps

##### min velocity / max velocity

<div align="center">

</div>

<i>Example of what the velocity curves look like if min velocity is set to 32 and max velocity to 95</i>

<i>Applies to the selected [output port/device](#portdevice-2) and [voice](#voice)</i>

* Turn the VAL/&harr; knob to **set a minimum or maximum of the output velocity range** [voice](#voice)
* Turn the VAL/&harr; knob to **adjust the velocity response dynamics** in three increasingly positive steps (&lsquo;positive 1&rsquo;, &lsquo;positive 2&rsquo;, &lsquo;positive 3&rsquo;) and three increasingly negative steps (&lsquo;negative 1&rsquo;, &lsquo;negative 2&rsquo;, &lsquo;negative 3&rsquo;) or select &lsquo;linear&rsquo; (the default) not to change the velocity (velocity out level = velocity in level)
* Press the DEL knob to **set the minimum velocity to 0 or the maximum velocity to 127**
* Minimum velocity sets the lowest value sent out when the input velocity is 0
* Maximum velocity sets the highest value sent out when the maximum velocity is 127

> [!NOTE]
> Minimum and maximum velocity are linked to the [velocity curve](#velocity-curve) setting: the velocity curve is scaled to the output range set by minimum and maximum velocity.

> [!IMPORTANT]
> MIDI velocity only has a resolution of 127 steps (1 to 127 &ndash; 0 is note off). Adjusting the velocity curve significantly reduces that resolution and adjusting minimum and/or maximum velocity reduces it even further.
<br clear=right>

### &emsp;Tools

This page offers tools to quickly set up [toms](#14--assign-toms) or [multipad triggers](#24--multipad-select-mode) to the same output device/voice with different notes or chords (the latter only for multipad).

> [!NOTE]
> These assignment tools only work for voices which support different notes as input (pitched percussion or non-percussive voices).
<br clear=right>

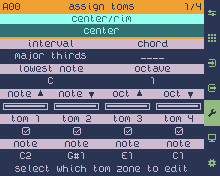
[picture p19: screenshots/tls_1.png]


#### &ensp;1/4 &ndash; assign toms

*See [assigning notes to toms](#assigning-notes-to-toms) for more instructions on how to use this tool.*

##### center/rim

* Turn the VAL/&harr; knob to **select toms&rsquo; trigger zone** (center or rim) to assign notes to
* Press the DEL knob to **set the trigger zone to center** (default)

##### interval

<i>Applies to the selected [zone](#centerrim) of the [selected toms](#tom-1-to-n)</i>

<ul>
<li>Turn the VAL/&harr; knob to <b>select an interval series</b> to use:</br></br>
<table>
<tr><td></td><td><b>Interval</b></td><td><b>Semitones</b></td></tr>
<tr><td rowspan=3><i>2 toms</i></td><td>perfect fourth</td><td>(0, 5)</td></tr>
<tr><td>perfect fifth</td><td>(0, 7)</td></tr>
<tr><td>major sixth</td><td>(0, 9)</td></tr>
<tr><td rowspan=3><i>3 toms</i></td><td>major thirds</td><td>(0, 4, 8)</td></tr>
<tr><td>perfect fourths</td><td>(0, 5, 10)</td></tr>
<tr><td>perfect fifths</td><td>(0, 7, 14)</td></tr>
<tr><td rowspan=5><i>4 toms</i></td><td>major thirds</td><td>(0, 4, 8, 12)</td></tr>
<tr><td>P4/P4/M3</td><td>(0, 4, 9, 14)</td></tr>
<tr><td>perfect fourths</td><td>(0, 5, 10, 15)</td></tr>
<tr><td>2x P4</td><td>(0, 5, 12, 17)</td></tr>
<tr><td>P4/P5/P5</td><td>(0, 7, 12, 17)</td></tr>
</table></li>
<li>The option &lsquo;____&rsquo; means that no interval is selected or detected</li>
<li>Notes can be set either based on intervals or based on a <a href="#chord">chord</a></li>
</ul>

> [!NOTE]
> Only those options can be selected which have the same number of notes as the number of [included toms](#tom-1-to-n).

##### chord

<i>Applies to the selected [zone](#centerrim) of the [selected toms](#tom-1-to-n)</i>

<ul>
<li>Turn the VAL/&harr; knob to <b>select a chord-based series</b> to use:</br></br>
<table>
<tr><td></td><td><b>Chord</b></td><td><b>Semitones</b></td></tr>
<tr><td rowspan=10><i>3 toms</i></td><td>diminished</td><td>(0, 3, 6)</td></tr>
<tr><td>minor</td><td>(0, 3, 7)</td></tr>
<tr><td>major </td><td>(0, 4, 7)</td></tr>
<tr><td>major (1st inv)</td><td>(0, 3, 8)</td></tr>
<tr><td>augmented</td><td>(0, 4, 8)</td></tr>
<tr><td>minor (2nd inv)</td><td>(0, 5, 8)</td></tr>
<tr><td>minor (1st inv)</td><td>(0, 4, 9)</td></tr>
<tr><td>major (2nd inv)</td><td>(0, 5, 9)</td></tr>
<tr><td>minor 7 (no 5)</td><td>(0, 3, 10)</td></tr>
<tr><td>major 7 (no 5)</td><td>(0, 4, 11)</td></tr>
<tr><td rowspan=11><i>4 toms</i></td><td>diminished 7</td><td>(0, 3, 6, 9)</td></tr>
<tr><td>minor 6</td><td>(0, 3, 7, 9)</td></tr>
<tr><td>major 6</td><td>(0, 4, 7, 9)</td></tr>
<tr><td>half-dim 7</td><td>(0, 3, 6, 10)</td></tr>
<tr><td>minor 7</td><td>(0, 3, 7, 10)</td></tr>
<tr><td>dominant 7</td><td>(0, 4, 7, 10)</td></tr>
<tr><td>augmented 7</td><td>(0, 4, 8, 10)</td></tr>
<tr><td>major 7</td><td>(0, 4, 7, 11)</td></tr>
<tr><td>minor/major 7</td><td>(0, 3, 7, 11)</td></tr>
<tr><td>minor</td><td>(0, 5, 8, 12)</td></tr>
<tr><td>major </td><td>(0, 5, 9, 12)</td></tr>
</table></li>
<li>The option &lsquo;____&rsquo; means that no chord is selected or detected</li>
<li>Notes can be set either based on <a href="#interval">intervals</a> or based on a chord</li>
</ul>

> [!NOTE]
> Only those options can be selected which have the same number of notes as the number of [included toms](#tom-1-to-n).

##### lowest note

<i>Applies to the selected [zone](#centerrim) of the [selected toms](#tom-1-to-n)</i>

* Turn the VAL/&harr; knob to **select the lowest note** (C to B) to assign
* Press the DEL knob to **clear the selected note** (set to &lsquo;__&rsquo;)

##### octave

<i>Applies to the selected [zone](#centerrim) of the [selected toms](#tom-1-to-n)</i>

* Turn the VAL/&harr; knob to **select the octave for the [lowest note](#lowest-note)** (-1 to 9)
* Press the DEL knob to **set the octave to 1** (default)

##### note &#x25B2; / note &#x25BC;

<i>Applies to the selected [zone](#centerrim) of the [selected toms](#tom-1-to-n)</i>

* Press the SEL/OPT knob to **transpose all notes one semitone up or down**

##### oct &#x25B2; / oct &#x25BC;

<i>Applies to the selected [zone](#centerrim) of the [selected toms](#tom-1-to-n)</i>

* Press the SEL/OPT knob to **transpose all notes one octave up or down** (12 semitones)

##### tom 1 to *n*

<i>Applies to the selected [zone](#centerrim) of the [selected toms](#tom-1-to-n)</i>

* Turn the VAL/&harr; knob or press the SEL/OPT knob to **switch between including () or excluding ()** a tom
* Press the DEL knob to **exclude a tom ()**

##### note 1 to *n*

<i>Applies to the selected [zone](#centerrim) of the [selected toms](#tom-1-to-n)</i>

* Turn the VAL/&harr; knob to **assign a note** (C-1 to G9)
* Press the DEL knob to **clear the selected note** (set to &lsquo;___&rsquo;)

> [!TIP]
> If a device doesn&rsquo;t respond to the notes your assigned as expected, try one octave lower or one octave higher. There is no official MIDI standard for octave numbers. Cybo-Drummer follows the Scientific Pitch Notation standard, which defines the middle C as C4, so in Cybo-Drummer MIDI note 60 is C4, but some manufacturers define MIDI note as C3 and some as C5.
>
> If [MIDI learn](#midi-learn) is turned on the note can also be set by playing a trigger/note from a device connected to the set [MIDI learn port](#midi-learn-port).
<br clear=right>

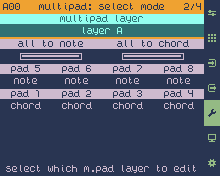
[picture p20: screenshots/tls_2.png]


#### &ensp;2/4 &ndash; multipad: select mode

*See [assigning single notes to multipad triggers](#assigning-single-notes-to-multipad-triggers) and [assigning chords to multipad triggers](#assigning-chords-to-multipad-triggers) for more instructions on how to use this tool.*

##### multipad layer

* Turn the VAL/&harr; knob to **select multipad&rsquo;s trigger layer** (layer A, layer B, layer C or layer D) to assign [notes](#34--multipad-assign-notes) or [chords](#44--multipad-assign-chords) to
* Press the DEL knob to **select trigger layer A** (default)

##### all to note

<i>Applies to the selected [multipad layer](#multipad-layer)</i>

* Press the SEL/OPT knob to **set all [pads](#pad-1-to-n) to &lsquo;chord&rsquo;**

##### all to chord

<i>Applies to the selected [multipad layer](#multipad-layer)</i>

* Press the SEL/OPT knob to **set all [pads](#pad-1-to-n) to &lsquo;note&rsquo;**

##### pad 1 to *n*

<i>Applies to the selected [multipad layer](#multipad-layer)</i>

* Turn the VAL/&harr; knob to **select whether a pad is included in [note assignment](#34--multipad-assign-notes)** (&lsquo;note&rsquo;), **[chord assignment](#44--multipad-assign-chords)** (&lsquo;chord&rsquo;) **or disabled from assignment** (&lsquo;____&rsquo;)
* Press the DEL knob to **exclude a pad** (set to &lsquo;____&rsquo;)
<br clear=right>

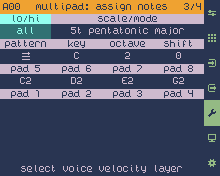
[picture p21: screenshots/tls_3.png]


#### &ensp;3/4 &ndash; multipad: assign notes

*See [assigning single notes to multipad triggers](#assigning-single-notes-to-multipad-triggers) for more instructions on how to use this tool.*

##### lo/hi

<i>Applies to [pads set to &lsquo;note&rsquo;](#pad-1-to-n) for the selected [multipad layer](#multipad-layer)</i>

* Turn the VAL/&harr; knob to **choose to which multipad [program layers](#portdevice--voice-a-to-d) to assign notes to based on [velocity layer(s)](#lohi-a-to-d)**:
  * *all:*&ensp;assign notes to all program layers, independently of their velocity layer settings
  * *low:*&ensp;assign notes only to program layers with the velocity layer set to &lsquo;low&rsquo; 
  * *high:*&ensp;assign notes only to program layers with the velocity layer set to &lsquo;high&rsquo;
* Press the DEL knob to **select assignment to all velocity layers** (set to &lsquo;all&rsquo;)

##### scale/mode

<i>Applies to [pads set to &lsquo;note&rsquo;](#pad-1-to-n) for the selected [multipad layer](#multipad-layer) and to selected [velocity layers](#lohi)</i>

<ul>
<li>Turn the VAL/&harr; knob to <b>select a scale or mode</b> to asign:</br></br>
<table>
<tr><td></td><td><b>Scale/Mode</b></td><td><b>Semitones</b></td></tr>
<tr><td rowspan=7><i>5-tone scale</i></td><td>5t pentatonic major</td><td>(0, 2, 4, 7, 8)</td></tr>
<tr><td>5t pentatonic minor</td><td>(0, 3, 5, 7, 10)</td></tr>
<tr><td>5t in</td><td>(0, 1, 5, 7, 8)</td></tr>
<tr><td>5t yo</td><td>(0, 2, 5, 7, 9)</td></tr>
<tr><td>5t hirajoshi</td><td>(0, 4, 6, 7, 11)</td></tr>
<tr><td>5t iwato</td><td>(0, 1, 5, 6, 10)</td></tr>
<tr><td>5t insen</td><td>(0, 1, 5, 7, 10)</td></tr>
<tr><td rowspan=3><i>6-tone scale</i></td><td>6t blues</td><td>(0, 3, 5, 6, 7, 10)</td></tr>
<tr><td>6t augmented</td><td>(0, 3, 4, 7, 8, 11)</td></tr>
<tr><td>6t whole note</td><td>(0, 2, 4, 6, 8, 10)</td></tr>
<tr><td rowspan=16><i>7-tone scale</i></td><td>7t major</td><td>(0, 2, 4, 5, 7, 9, 11)</td></tr>
<tr><td>7t natural minor</td><td>(0, 2, 3, 5, 7, 8, 10)</td></tr>
<tr><td>7t harmonic minor</td><td>(0, 2, 3, 5, 7, 8, 11)</td></tr>
<tr><td>7t asc melodic minor</td><td>(0, 2, 3, 5, 7, 9, 11)</td></tr>
<tr><td>7t harmonic major</td><td>(0, 2, 4, 5, 7, 8, 11)</td></tr>
<tr><td>7t double harmonic</td><td>(0, 1, 4, 5, 7, 8, 11)</td></tr>
<tr><td>7t altered</td><td>(0, 1, 3, 4, 6, 8, 10)</td></tr>
<tr><td>7t hungarian minor</td><td>(0, 2, 3, 6, 7, 8, 11)</td></tr>
<tr><td>7t hungarian major</td><td>(0, 3, 4, 6, 7, 9, 10)</td></tr>
<tr><td>7t locrian major</td><td>(0, 2, 4, 5, 6, 8, 10)</td></tr>
<tr><td>7t ukrainian dorian</td><td>(0, 2, 3, 6, 7, 9, 10)</td></tr>
<tr><td>7t phrygian dominant</td><td>(0, 1, 4, 5, 7, 8, 10)</td></tr>
<tr><td>7t acoustic</td><td>(0, 2, 4, 6, 7, 9, 10)</td></tr>
<tr><td>7t persian</td><td>(0, 1, 4, 5, 6, 8, 11)</td></tr>
<tr><td>7t half diminished</td><td>(0, 2, 3, 5, 6, 8, 10)</td></tr>
<tr><td>7t lydian augmented</td><td>(0, 2, 4, 6, 8, 9, 11)</td></tr>
<tr><td rowspan=7><i>8-tone scale</i></td><td>8t octatonic (I)</td><td>(0, 2, 3, 5, 6, 7, 8, 11)</td></tr>
<tr><td>8t octatonic (II)</td><td>(0, 1, 3, 4, 6, 7, 9, 10)</td></tr>
<tr><td>8t bebop dominant</td><td>(0, 2, 4, 6, 7, 9, 10, 11)</td></tr>
<tr><td>8t bebop major</td><td>(0, 2, 4, 5, 7, 8, 9, 11)</td></tr>
<tr><td>8t bebop mel minor</td><td>(0, 2, 3, 5, 7, 8, 9, 11)</td></tr>
<tr><td>8t bebop harm minor</td><td>(0, 2, 3, 5, 7, 9, 10, 11)</td></tr>
<tr><td>8t 7th flat 5 dim</td><td>(0, 2, 4, 5, 6, 9, 10, 11)</td></tr>
<tr><td><i>9-tone scale</i></td><td>9t melodic minor</td><td>(0, 2, 3, 5, 7, 8, 9, 10, 11)</td></tr>
<tr><td><i>12-tone scale</i></td><td>12t chromatic</td><td>(0, 1, 2, 3, 4, 5, 6, 7, 8, 9, 10, 11)</td></tr>
<tr><td rowspan=8><i>Mode</i></td><td>ionian mode (I)</td><td>(0, 2, 4, 5, 7, 9, 11)</td></tr>
<tr><td>dorian mode (II)</td><td>(0, 2, 3, 5, 7, 9, 10)</td></tr>
<tr><td>phrygian mode (III)</td><td>(0, 1, 3, 5, 7, 8, 10)</td></tr>
<tr><td>lydian mode (IV)</td><td>(0, 2, 4, 6, 7, 9, 11)</td></tr>
<tr><td>mixolydian mode (V)</td><td>(0, 2, 4, 5, 7, 9, 10)</td></tr>
<tr><td>aeolian mode (VI)</td><td>(0, 2, 3, 5, 7, 8, 10)</td></tr>
<tr><td>locrian mode (VII)</td><td>(0, 1, 3, 5, 6, 8, 10)</td></tr>
<tr><td>flamenco mode</td><td>(0, 1, 4, 5, 7, 8, 11)</td></tr>
</table></li>
<li>The option &lsquo;____&rsquo; means that no scale or mode is selected or detected</li>
<li>Press the DEL knob to <b>select the major scale</b>** (default)</li>
</ul>

##### pattern

<i>Applies to [pads set to &lsquo;note&rsquo;](#pad-1-to-n) for the selected [multipad layer](#multipad-layer) and to selected [velocity layers](#lohi)</i>

* Turn the VAL/&harr; knob to **set the direction in which notes are assigned**:
  * *__:*&ensp;off &ndash; no assignment pattern selected or detected
  * *:*&ensp;assign notes first up and then right 
  * *:*&ensp;assign notes first right and then up

##### key

<i>Applies to [pads set to &lsquo;note&rsquo;](#pad-1-to-n) for the selected [multipad layer](#multipad-layer) and to selected [velocity layers](#lohi)</i>

* Turn the VAL/&harr; knob to **select the key** (C to B) for the [scale or mode](#scalemode)
* Press the DEL knob to **clear the selected note** (set to &lsquo;__&rsquo;)

##### octave

<i>Applies to [pads set to &lsquo;note&rsquo;](#pad-1-to-n) for the selected [multipad layer](#multipad-layer) and to selected [velocity layers](#lohi)</i>

* Turn the VAL/&harr; knob to **select the octave for the [key](#key)** (-1 to 9)
* Press the DEL knob to **set the octave to 1** (default)

##### shift

<i>Applies to [pads set to &lsquo;note&rsquo;](#pad-1-to-n) for the selected [multipad layer](#multipad-layer) and to selected [velocity layers](#lohi)</i>

* Turn the VAL/&harr; knob to **shift the root note (tonic) position left/down** (negative number) **or right/up** (positive number)
* Press the DEL knob to **set shift to 0** (no shift &ndash; the root note (tonic) is the first included pad counting from the bottom left following the selected [pattern](#pattern))
* The minimum and maximum value which can be selected depends on the number of tones in the selected [scale/mode](#scalemode)

##### pad 1 to *n*

<i>Applies to [pads set to &lsquo;note&rsquo;](#pad-1-to-n) for the selected [multipad layer](#multipad-layer) and to selected [velocity layers](#lohi)</i>

* Turn the VAL/&harr; knob to **assign a note** (C-1 to G9)
* Press the DEL knob to **clear the selected note** (set to &lsquo;___&rsquo;)

> [!TIP]
> If a device doesn&rsquo;t respond to the notes your assigned as expected, try one octave lower or one octave higher. There is no official MIDI standard for octave numbers. Cybo-Drummer follows the Scientific Pitch Notation standard, which defines the middle C as C4, so in Cybo-Drummer MIDI note 60 is C4, but some manufacturers define MIDI note as C3 and some as C5.
>
> If [MIDI learn](#midi-learn) is turned on the note can also be set by playing a trigger/note from a device connected to the set [MIDI learn port](#midi-learn-port).
<br clear=right>



#### &ensp;4/4 &ndash; multipad: assign chords

*See [assigning chords to multipad triggers](#assigning-chords-to-multipad-triggers) for more instructions on how to use this tool.*

##### note &#x25B2; / note &#x25BC;

<i>Applies to [pads set to &lsquo;chord&rsquo;](#pad-1-to-n) for the selected [multipad layer](#multipad-layer)</i>

* Press the SEL/OPT knob to **transpose all chords one semitone up or down** for the selected [layer]("#multipad-layer") of the [selected multipad triggers](#pad-1-to-n)

##### octave &#x25B2; / octave &#x25BC;

<i>Applies to [pads set to &lsquo;chord&rsquo;](#pad-1-to-n) for the selected [multipad layer](#multipad-layer)</i>

* Press the SEL/OPT knob to **transpose all chords one octave up or down** (12 semitones) for the selected [layer]("#multipad-layer") of the [selected multipad triggers](#pad-1-to-n)
<br clear=right>



##### pad 1 to *n*

<i>Applies to [pads set to &lsquo;chord&rsquo;](#pad-1-to-n) for the selected [multipad layer](#multipad-layer)</i>

<ul>
<li>Press the SEL/OPT knob &#9312; to <b>open a chord selection pop-up</b></li>
<li>In the chord selection pop-up:<ul>
  <li>Turn the NAV/&varr; knob &#9313; to switch between &lsquo;root&rsquo;, &lsquo;octave&rsquo;, &lsquo;chord quality&rsquo; and &lsquo;inversion&rsquo;</li>
  <li>Turn the VAL/&harr; knob &#9314; to select a value:<ul>
    <li><i>root:</i>&ensp;select the chord&rsquo;s root note (C to B)</li>
    <li><i>octave:</i>&ensp;select the chord&rsquo;s root note&rsquo;s octave (-1 to 9)</li>
    <li><i>chord quality:</i>&ensp;select one of the following types of chord:<table>
    <tr><td><b>Long Notation</b></td><td><b>Short Notation</b></td><td><b>Semitones</b></td></tr>
    <tr><td>major</td><td></td><td>(0, 4, 7)</td></tr>
    <tr><td>minor</td><td>m</td><td>(0, 3, 7)</td></tr>
    <tr><td>fifth ('power chord')</td><td>5</td><td>(0, 7)</td></tr>
    <tr><td>dominant seventh</td><td>7</td><td>(0, 4, 7, 10)</td></tr>
    <tr><td>major seventh</td><td>M7</td><td>(0, 4, 7, 11)</td></tr>
    <tr><td>minor seventh</td><td>m7</td><td>(0, 3, 7, 10)</td></tr>
    <tr><td>minor major seventh</td><td>nM7</td><td>(0, 3, 7, 11)</td></tr>
    <tr><td>suspended fourth</td><td>sus</td><td>(0, 5, 7)</td></tr>
    <tr><td>suspended second</td><td>sus2</td><td>(0, 2, 7)</td></tr>
    <tr><td>dominant 7th susp. 4th</td><td>7sus</td><td>(0, 5, 7, 10)</td></tr>
    <tr><td>dominant 7th susp. 2nd</td><td>7s2</td><td>(0, 2, 7, 10)</td></tr>
    <tr><td>major added-second</td><td>add2</td><td>(0, 2, 4, 7)</td></tr>
    <tr><td>major added-ninth</td><td>add9</td><td>(0, 4, 7, 14)</td></tr>
    <tr><td>major added-fourth</td><td>add4</td><td>(0, 4, 5, 7)</td></tr>
    <tr><td>major added-eleventh</td><td>a11</td><td>(0, 4, 7, 17)</td></tr>
    <tr><td>minor added-second</td><td>ma2</td><td>(0, 3, 4, 7)</td></tr>
    <tr><td>minor added-ninth</td><td>ma9</td><td>(0, 3, 7, 14)</td></tr>
    <tr><td>minor added-fourth</td><td>ma4</td><td>(0, 3, 5, 7)</td></tr>
    <tr><td>minor added-eleventh</td><td>ma11</td><td>(0, 3, 7, 17)</td></tr>
    <tr><td>suspended 4th added-2nd</td><td>s4a9</td><td>(0, 2, 5, 7)</td></tr>
    <tr><td>suspended 4th added-9th</td><td>s4a9</td><td>(0, 5, 7, 14)</td></tr>
    <tr><td>major sixth</td><td>6</td><td>(0, 4, 7, 9)</td></tr>
    <tr><td>minor sixth</td><td>m6</td><td>(0, 3, 7, 9)</td></tr>
    <tr><td>diminished</td><td>dim</td><td>(0, 3, 6)</td></tr>
    <tr><td>deminished seventh</td><td>dim7</td><td>(0, 3, 6, 9)</td></tr>
    <tr><td>augmented</td><td>aug</td><td>(0, 4, 8)</td></tr>
    <tr><td>dominant 7th flat 5</td><td>7b5</td><td>(0, 4, 6, 10)</td></tr>
    <tr><td>7th sharp 5 / augmented 7th</td><td>7#5</td><td>(0, 4, 8, 10)</td></tr>
    <tr><td>minor 7 flat 5/half dim 7th</td><td>m7b5</td><td>(0, 3, 6, 10)</td></tr>
    <tr><td>major 7th sharp 5</td><td>M7#5</td><td>(0, 4, 8, 11)</td></tr>
    <tr><td>minor 7th sharp 5</td><td>m7#5</td><td>(0, 3, 8, 10)</td></tr>
    </table></li>
    <li><i>inversion:</i>&ensp;select which <a href="https://en.wikipedia.org/wiki/Inversion_(music)#Root_position_and_inverted_chords">inversion</a> of the chord (&rsquo;root position&rsquo; is the default form of the chord, without inversion, with the root noot as the lowest note in the chord &ndash; the number of inversions depends on the number of notes in the chord)</li></ul></li>
  <li>Press the SEL/OPT knob &#9312; or the YES button &#9315; to confirm (or press the NO button &#9316; to cancel without changes)</li></ul></li>
  <li>A chord will only be assigned if a root, octave and chord quality all have been selected
  <li>The pad selection block will show the assigned chord in a short format existing of root note, short chord quality notation (see table above) and octave between brackets &ndash; for example: &lsquo;CM7[4]&rsquo; means a C major seventh chord with the root in the 4th octave
</ul>
<br clear=right>

### &emsp;Monitor

Use the monitor page to monitor the router, MIDI data coming in or MIDI data going out.
<br clear=right>



#### &ensp;1/3 &ndash; monitor routing

* Shows what is going on in the router
* Display format: &lsquo;Input Device Trigger/Zone > Output Device Voice&rsquo; (for example: `2Box BD > Drumbrute Kick 1`)

> [!NOTE]
> If an input preset triggers more than one output presets the router will show as many lines as output presets are triggers.
<br clear=right>



#### &ensp;2/3 &ndash; monitor MIDI in

* Shows the MIDI data coming in from any of the MIDI input ports
* Display format: &lsquo;P0 C00 MessageName data [HH HH HH]&rsquo;, where
  * *P0* is the input port (P1 to P6)
  * *C00* is the input channel (C 1 to C16) &ndash; not shown for system common messages
  * *MessageData* is the name of the MIDI message (for example &lsquo;NoteOn&rsquo;)
  * *data* is one or two data values (for example for note on or note off: note and velocity)
  * *[HH HH HH]* is the raw MIDI message in hexadecimal format

> [!NOTE]
> SysEx (system exclusive) data is filtered out by the router and won&rsquo;t show, MIDI clock data and active sensing are filtered out by the monitor and won&rsquo;t show either.
<br clear=right>



#### &ensp;3/3 &ndash; monitor MIDI out

* Shows the MIDI data sent out to any of the MIDI input ports
* Display format: &lsquo;P0 C00 MessageName data [HH HH HH]&rsquo;, where
  * *P0* is the output port (P1 to P6)
  * *C00* is the output channel (C 1 to C16) &ndash; not shown for system common messages
  * *MessageData* is the name of the MIDI message (for example &lsquo;NoteOn&rsquo;)
  * *data* is one or two data values (for example for note on or note off: note and velocity)
  * *[HH HH HH]* is the raw MIDI message in hexadecimal format

> [!NOTE]
> MIDI clock data and active sensing are filtered out by the monitor and won&rsquo;t show.
<br clear=right>

### &emsp;Settings

Use the settings page to adjust global settings, to back up or recover data or to find the firmware version number.
<br clear=right>

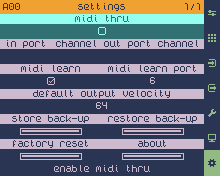
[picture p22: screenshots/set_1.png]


#### &ensp;1/1 &ndash; settings

##### midi thru

* Turn the VAL/&harr; knob or press the SEL/OPT knob to **switch between MIDI thru on ()** to enable MIDI thru from the set input port/channel to the set output port/channel, **and off ()** to disable MIDI thru
* Press the DEL knob to **turn MIDI thru off ()**

> [!NOTE]
> MIDI thru needs input port, input channel, output port and output channel to be specified to work.
>
> SysEx (system exclusive) data is filtered out by the router and will not be sent to the MIDI thru output port.

##### in port / channel

* Turn the VAL/&harr; knob to **select an input port** (1 to 6) **/ input MIDI channel** (1 to 16) to receive MIDI data from to be sent to the MIDI thru output port
* Press the DEL knob to **clear port / channel setting** (set to &lsquo;__&rsquo;)

> [!NOTE]
> Some MIDI devices number MIDI channels 1 to 16, some number them 0 to 15 &ndash; in the latter case you need to set a one position higher channel value on Cybo-Drummer, compared to the input device&rsquo;s number. 

##### out port / channel

* Turn the VAL/&harr; knob to **select an output port** (1 to 6) **/ output MIDI channel** (1 to 16) to send MIDI data to which is received from the MIDI thru output port
* Press the DEL knob to **clear port / channel setting** (set to &lsquo;__&rsquo;)

> [!NOTE]
> Some MIDI devices number MIDI channels 1 to 16, some number them 0 to 15 &ndash; in the latter case you need to set a one position higher channel value on Cybo-Drummer, compared to the output device&rsquo;s number. 

##### midi learn

* Turn the VAL/&harr; knob or press the SEL/OPT knob to **switch between MIDI learn on () and off ()**
* Press the DEL knob to **turn MIDI learn off ()**

> [!NOTE]
> MIDI learn needs midi learn port to be specified to work.

> [!TIP]
> Connect the MIDI out of a drum computer to MIDI learn port and press the trigger button on it for each sound to easily assign drum triggers.

##### midi learn port

* Set from which input port (1 to 6) to receive MIDI data to be used for MIDI learn

* Turn the VAL/&harr; knob to **select an input port** (1 to 6) to receive MIDI data from to be used for MIDI learn
* Press the DEL knob to **clear port setting** (set to &lsquo;__&rsquo;)

##### default output velocity

* Turn the VAL/&harr; knob to **set the default velocity** (0 to 127) used when pressing the TRIGGER button
* Press the DEL knob to **set the default output velocity to 64**

##### store back-up

* Press the SEL/OPT knob to **store all programs, device/trigger/voice definitions and settings to back-up files**
* Device/trigger/voice definitions and settings from `data_files/data.json` are copied to `data_files/back_up.json` and program files from the `data_files/programs/` folder are copied to `data_files/programs_bak/`

##### restore back-up

* Press the SEL/OPT knob to **restore all programs, device/trigger/voice definitions and settings from previously stored back-up files** (if any)
* See [store back-up](#store-back-up) for details on where back-up files are stored

##### factory reset

* Press the SEL/OPT knob to **restore all programs, device/trigger/voice definitions and settings to initial values**
* Initial values consist of default settings and empty lists of programs, devices, triggers and voices

##### about

* Press the SEL/OPT knob to **show what version of Cybo-Drummer you&rsquo;re using**
<br clear=right>

## Triggers and Zones/Layers

<table>
<tr><td colspan=2><b>Trigger</b></td><td colspan=2><b>Zones/Layers</b></td></tr>
<tr><td><b>Symbol</b></td><td><b>Name</b></td><td colspan=2><b>Name (Symbol)</b></td></tr>
<tr><td>BD</td><td>base drum</td><td rowspan=2>n/a</td></tr>
<tr><td>B2</td><td>base drum 2</td></tr>
<tr><td>SD</td><td>snare drum</td><td>center (), rim ()</td></tr>
<tr><td>T1</td><td>tom 1</td><td rowspan=9>center (), rim ()</td></tr>
<tr><td>T2</td><td>tom 2</td></tr>
<tr><td>T3</td><td>tom 3</td></tr>
<tr><td>T4</td><td>tom 4</td></tr>
<tr><td>T5</td><td>tom 5</td></tr>
<tr><td>T6</td><td>tom 6</td></tr>
<tr><td>T7</td><td>tom 7</td></tr>
<tr><td>T8</td><td>tom 8</td></tr>
<tr><td>T9</td><td>tom 9</td></tr>
<tr><td>P1</td><td>percussion 1</td><td rowspan=9>center (), rim ()</td></tr>
<tr><td>P2</td><td>percussion 2</td></tr>
<tr><td>P3</td><td>percussion 3</td></tr>
<tr><td>P4</td><td>percussion 4</td></tr>
<tr><td>P5</td><td>percussion 5</td></tr>
<tr><td>P6</td><td>percussion 6</td></tr>
<tr><td>P7</td><td>percussion 7</td></tr>
<tr><td>P8</td><td>percussion 8</td></tr>
<tr><td>P9</td><td>percussion 9</td></tr>
<tr><td>HO</td><td>open hihat</td><td rowspan=3>edge (), bow (), foot ()</td></tr>
<tr><td>HH</td><td>half-open hihat</td></tr>
<tr><td>HC</td><td>closed hihat</td></tr>
<tr><td>RD</td><td>ride cymbal</td><td>edge (), bow (), bell (), choke ()</td></tr>
<tr><td>C1</td><td>crash/cymbal 1</td><td rowspan=9>edge (), bow (), bell (), choke ()</td></tr>
<tr><td>C2</td><td>crash/cymbal 2</td></tr>
<tr><td>C3</td><td>crash/cymbal 3</td></tr>
<tr><td>C4</td><td>crash/cymbal 4</td></tr>
<tr><td>C5</td><td>crash/cymbal 5</td></tr>
<tr><td>C6</td><td>crash/cymbal 6</td></tr>
<tr><td>C7</td><td>crash/cymbal 7</td></tr>
<tr><td>C8</td><td>crash/cymbal 8</td></tr>
<tr><td>C9</td><td>crash/cymbal 9</td></tr>
<tr><td>M1</td><td>multipad 1</td><td rowspan=12>layer A (), layer B (), layer C (), layer D ()</td></tr>
<tr><td>M2</td><td>multipad 2</td></tr>
<tr><td>M3</td><td>multipad 3</td></tr>
<tr><td>M4</td><td>multipad 4</td></tr>
<tr><td>M5</td><td>multipad 5</td></tr>
<tr><td>M6</td><td>multipad 6</td></tr>
<tr><td>M7</td><td>multipad 7</td></tr>
<tr><td>M8</td><td>multipad 8</td></tr>
<tr><td>M9</td><td>multipad 9</td></tr>
<tr><td>MA</td><td>multipad 10</td></tr>
<tr><td>MB</td><td>multipad 11</td></tr>
<tr><td>MC</td><td>multipad 12</td></tr>
<tr><td>A1</td><td>additional trig. 1</td><td rowspan=9>center (), rim ()</td></tr>
<tr><td>A2</td><td>additional trig. 2</td></tr>
<tr><td>A3</td><td>additional trig. 3</td></tr>
<tr><td>A4</td><td>additional trig. 4</td></tr>
<tr><td>A5</td><td>additional trig. 5</td></tr>
<tr><td>A6</td><td>additional trig. 6</td></tr>
<tr><td>A7</td><td>additional trig. 7</td></tr>
<tr><td>A8</td><td>additional trig. 8</td></tr>
<tr><td>A9</td><td>additional trig. 9</td></tr>
</table>

</main>

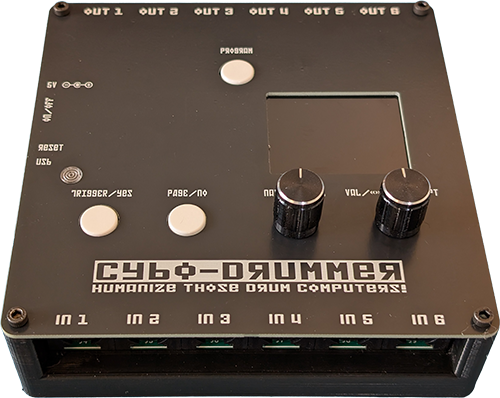
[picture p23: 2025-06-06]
images/fully_assembled.png

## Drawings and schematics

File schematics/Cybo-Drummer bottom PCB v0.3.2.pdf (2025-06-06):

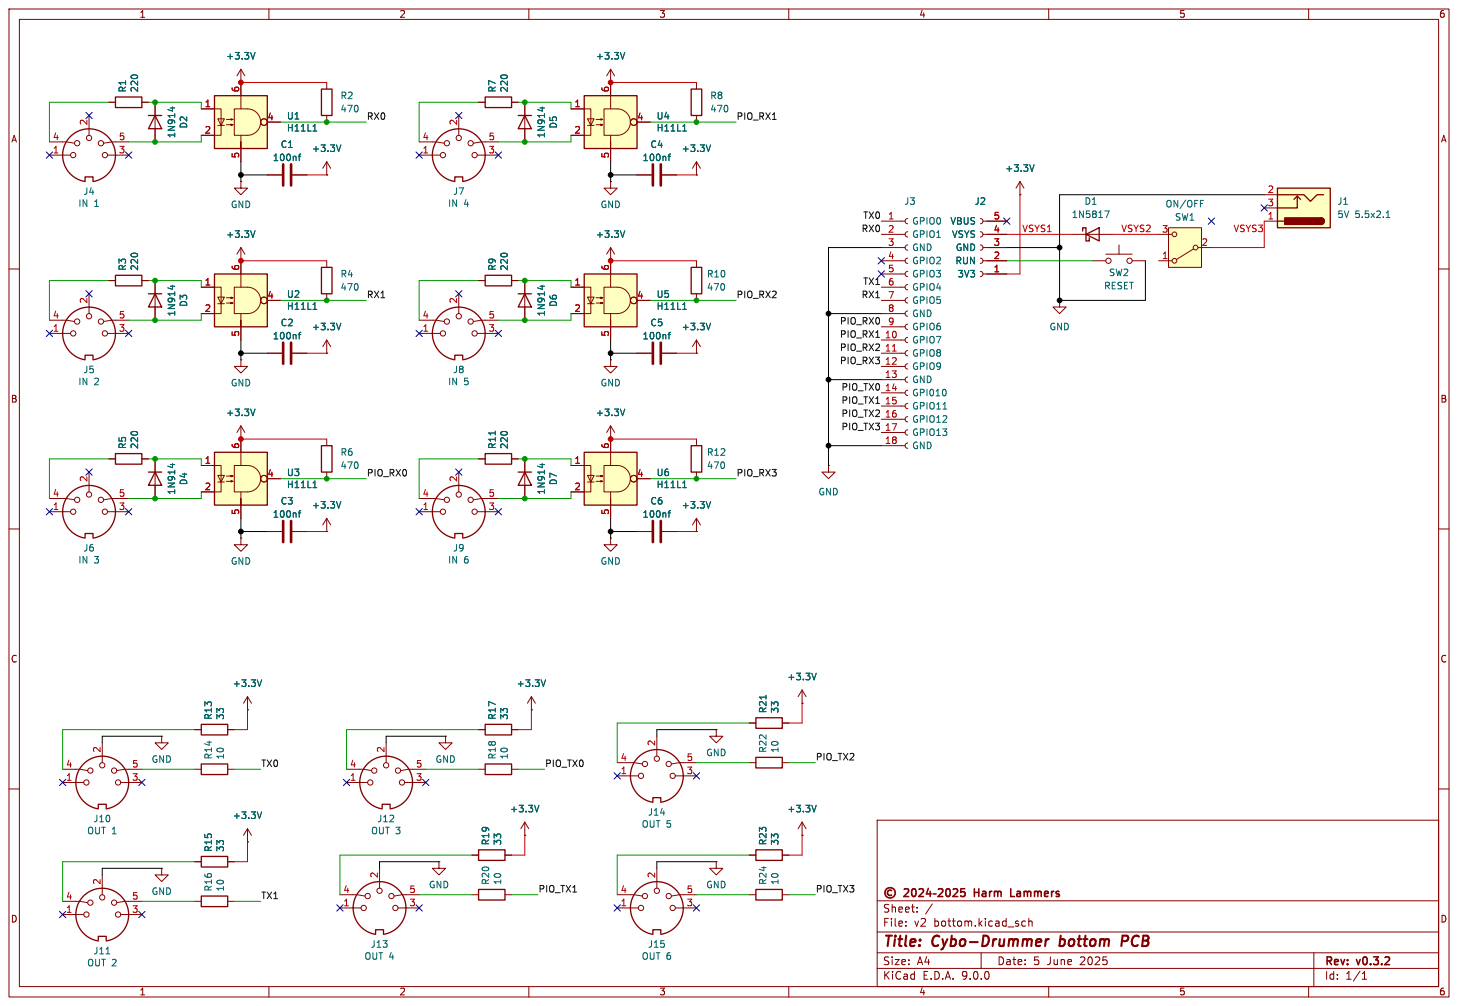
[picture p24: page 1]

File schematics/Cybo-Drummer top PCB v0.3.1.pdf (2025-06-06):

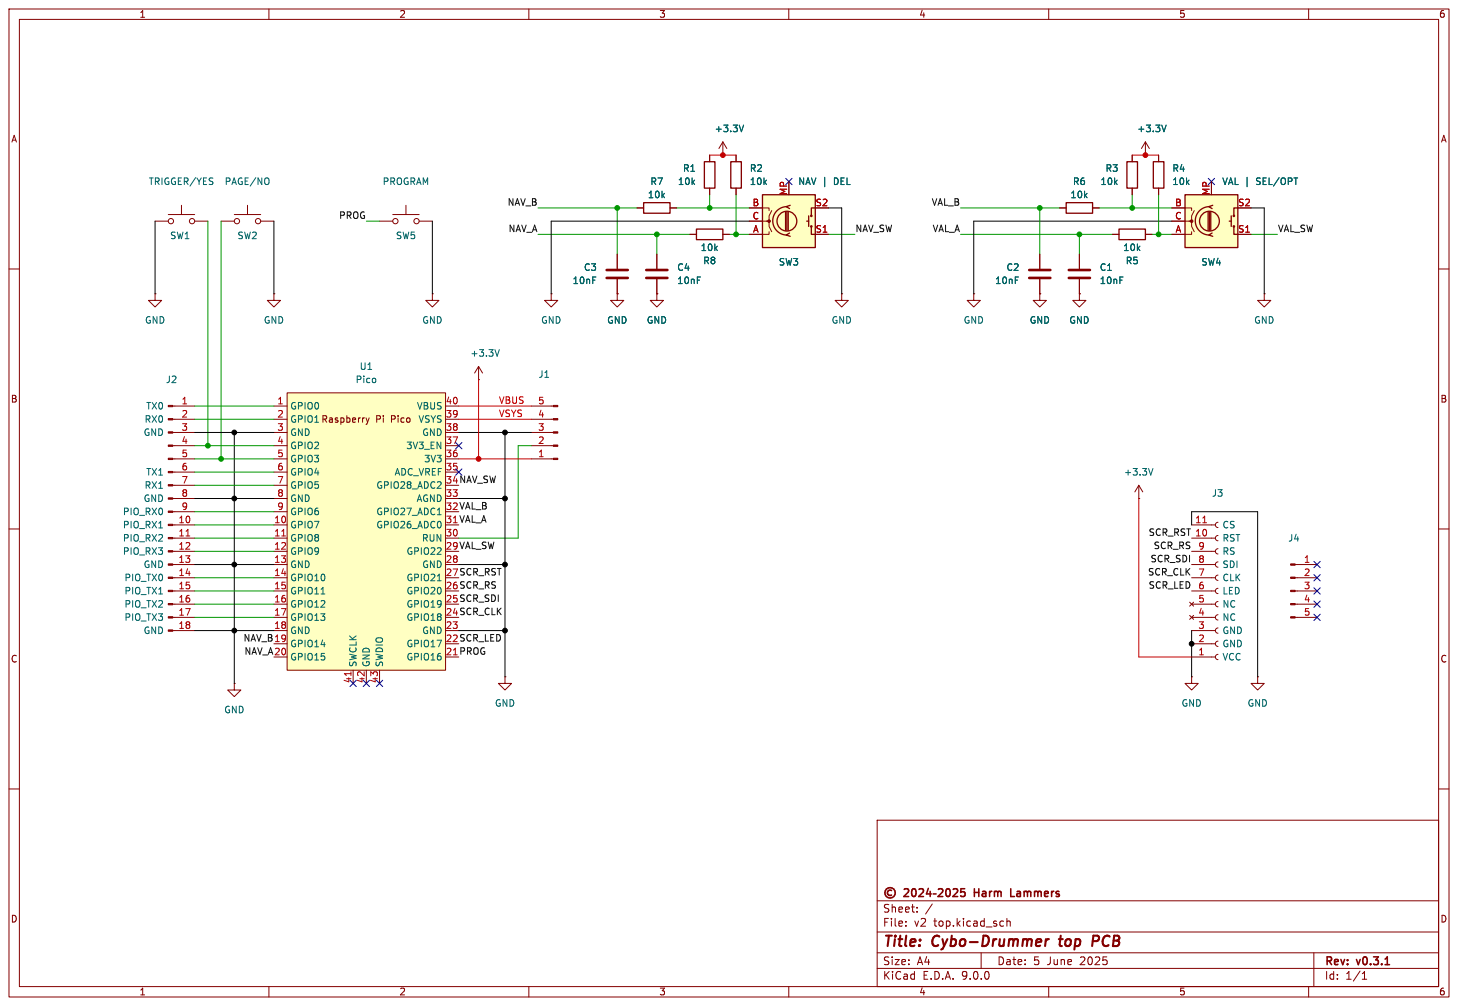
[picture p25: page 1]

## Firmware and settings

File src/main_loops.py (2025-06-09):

''' Main loop fuctions for Cybo-Drummer - Humanize Those Drum Computers!
    https://github.com/HLammers/cybo-drummer
    Copyright (c) 2024-2025 Harm Lammers

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
    You should have received a copy of the GNU General Public License along with this program. If not, see https://www.gnu.org/licenses/.'''

_PULSE = False

import micropython
import _thread
import machine
import time
import gc
from sys import exit

# global variables to store thread lock, ui instance, data instance and router instance
thread_lock = _thread.allocate_lock()
ui = None
data = None
router = None

from router import Router
import ui as ui_lib
from data import Data

_NONE                = const(-1)

_MAIN_LOOP_DELAY     = const(1) # ms
_SECOND_THREAD_DELAY = const(1000) # ms
_PULSE_DELAY         = const(5000) # ms

_OVERCLOCK_FREQ      = const(300_000_000) # Hz

def init() -> None:
    '''initiations before starting main loops'''
    global ui, data, router
    # initiate
    machine.freq(_OVERCLOCK_FREQ)
    _gc = gc
    _gc_collect = _gc.collect
    _gc_threshold = _gc.threshold
    _gc_mem_free = _gc.mem_free
    _gc_mem_alloc = _gc.mem_alloc
    _gc.enable()
    _gc_collect()
    _gc_threshold(_gc_mem_free() // 4 + _gc_mem_alloc())
    if __debug__: micropython.alloc_emergency_exception_buf(100)
    ui = ui_lib.UI()
    _gc_collect()
    _gc_threshold(_gc_mem_free() // 4 + _gc_mem_alloc())
    data = Data()
    data.load_data_json_file()
    _gc_collect()
    _gc_threshold(_gc_mem_free() // 4 + _gc_mem_alloc())
    router = Router()
    _gc_collect()
    _gc_threshold(_gc_mem_free() // 4 + _gc_mem_alloc())
    _thread.start_new_thread(second_thread, ())
    # call update to load data
    router.update(already_waiting=True)
    _gc_collect()
    _gc_threshold(_gc_mem_free() // 4 + _gc_mem_alloc())
    # draw screen
    ui.display.draw_screen()
    with thread_lock:
        router.start_second_thread = True

def main():
    '''main loop running on fist core, taking care of non time sensitive tasks: ui and processing encoders, user input, midi learn data and
    monitor data'''
    _process_encoder_input = ui.process_encoder_input # type: ignore
    _process_user_input = ui.process_user_input # type: ignore
    _read_midi_learn_data = router.read_midi_learn_data # type: ignore
    _process_midi_learn_data = ui.process_midi_learn_data # type: ignore
    _process_monitor = ui.process_monitor # type: ignore
    _process_program_change_break = router.process_program_change_break # type: ignore
    _draw_screen = ui.display.draw_screen # type: ignore
    previous_midi_learn_data = None
    _time = time
    _ticks_ms = _time.ticks_ms
    _ticks_diff = _time.ticks_diff
    _sleep_ms = _time.sleep_ms
    if _PULSE:
        last_pulse = _ticks_ms()
    last_loop = _ticks_ms()
    while True:
        _sleep_ms(_MAIN_LOOP_DELAY)
        last_loop = _ticks_ms()
        if _PULSE and _ticks_diff(last_loop, last_pulse) > _PULSE_DELAY:
            print('main thread pulse')
            last_pulse = last_loop
        # limit main loop speed to improve stability
        time.sleep_ms(_MAIN_LOOP_DELAY)
        ui.check_sleep_time_out() # type: ignore
        # process encoders
        redraw = _process_encoder_input()
        # process buttons and other input
        redraw |= _process_user_input()
        # process midi learn input
        if (midi_learn_data := _read_midi_learn_data()) is not None:
            if midi_learn_data != previous_midi_learn_data:
                previous_midi_learn_data = midi_learn_data
        if previous_midi_learn_data is not None:
            redraw |= _process_midi_learn_data(previous_midi_learn_data)
            previous_midi_learn_data = None
        # process router and midi monitor
        redraw |= _process_monitor()
        # process program change break
        _process_program_change_break()
        if redraw:
            _draw_screen()

def second_thread() -> None:
    '''time sensitive loop running on second core, taking care of midi routing'''
    print('second thread: wait')
    _router = router
    while _router is None:
        pass
    while _router.start_second_thread:
        pass
    print('second thread: initiate')
    input_ports = _router.midi_ports.input_ports # type: ignore
    _process_timed_note_off_events = _router.process_timed_note_off_events # type: ignore
    routes = _router.routes # type: ignore
    _trigger_note_on = _router.trigger_note_on # type: ignore
    _led = machine.Pin(25, machine.Pin.OUT)
    _led_on = _led.on
    _led_off = _led.off
    _thread_lock = thread_lock
    print('second thread: start')
    _time = time
    _ticks_ms = _time.ticks_ms
    _ticks_diff = _time.ticks_diff
    _time.sleep_ms(_SECOND_THREAD_DELAY)
    while not _router.terminated:
        _led_on()
        # check if first thread asks to wait (handshake)
        if _router.request_wait: # type: ignore
            _led_off()
            with _thread_lock:
                _router.running = False # type: ignore
                _router.request_wait = False # type: ignore
        if _PULSE:
            last_pulse = _ticks_ms()
        while _router.running and not _router.request_wait: # type: ignore
            if _PULSE and _ticks_diff(_ticks_ms(), last_pulse) > _PULSE_DELAY:
                print('second thread pulse')
                last_pulse = _ticks_ms()
            _led_on()
            # process midi input
            for port in input_ports:
                port.process()
            # process timed note off events
            _process_timed_note_off_events()
            # process trigger button input
            if (trigger := _router.ui_trigger) is not None: # type: ignore
                with _thread_lock:
                    _router.ui_trigger = None # type: ignore
                for route in routes[trigger]:
                    if (note := route['output_note']) == _NONE:
                        note = 60 # middle C
                    note_off = route['note_off']
                    _trigger_note_on(route['output_port'], route['output_channel'], note, note_off)
        _led_off()
    _thread.exit()
    print('second thread: terminated')

def shut_down() -> None:
    '''shutting down function'''
    global ui, router
    with thread_lock:
        router.terminated = True # type: ignore
        now = time.ticks_ms()
        while time.ticks_diff(time.ticks_ms(), now) < 500:
            pass
    ui.delete() # type: ignore
    data.delete() # type: ignore
    del ui
    router.delete() # type: ignore
    del router
    print('finished shutting down')
    exit()

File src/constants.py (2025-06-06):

''' Library providing constant tuples for Cybo-Drummer - Humanize Those Drum Computers!
    https://github.com/HLammers/cybo-drummer
    Copyright (c) 2024-2025 Harm Lammers

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
    You should have received a copy of the GNU General Public License along with this program. If not, see https://www.gnu.org/licenses/.'''

from data_types import ChainMapTuple, GenOptions

NOTES                = ('C', 'C#', 'D', 'D#', 'E', 'F', 'F#', 'G', 'G#', 'A', 'A#', 'B')

import midi_tools as mt

_NONE                 = const(-1)

_FONT_FIRST_PAGE      = const(131)
_FONT_FIRST_ZONE      = const(145)
_FONT_FIRST_TRANSIENT = const(155)
_FONT_FIRST_CURVE     = const(163)
_FONT_FIRST_PATTERN   = const(178)

_PAGE_PROGRAM         = const(1)
_PAGE_MATRIX          = const(2)
_PAGE_INPUT           = const(3)
_PAGE_OUTPUT          = const(4)
_PAGE_TOOLS           = const(5)
_PAGE_MONITOR         = const(6)
_PAGE_SETTINGS        = const(7)

_ICON_PROGRAM         = chr(_FONT_FIRST_PAGE) + chr(_FONT_FIRST_PAGE + 1)
_ICON_MATRIX          = chr(_FONT_FIRST_PAGE + 2) + chr(_FONT_FIRST_PAGE + 3)
_ICON_INPUT           = chr(_FONT_FIRST_PAGE + 4) + chr(_FONT_FIRST_PAGE + 5)
_ICON_OUTPUT          = chr(_FONT_FIRST_PAGE + 6) + chr(_FONT_FIRST_PAGE + 7)
_ICON_TOOLS           = chr(_FONT_FIRST_PAGE + 8) + chr(_FONT_FIRST_PAGE + 9)
_ICON_MONITOR         = chr(_FONT_FIRST_PAGE + 10) + chr(_FONT_FIRST_PAGE + 11)
_ICON_SETTINGS        = chr(_FONT_FIRST_PAGE + 12) + chr(_FONT_FIRST_PAGE + 13)

MAIN_FRAMES           = (_PAGE_PROGRAM, _PAGE_MATRIX, _PAGE_INPUT, _PAGE_OUTPUT, _PAGE_TOOLS, _PAGE_MONITOR, _PAGE_SETTINGS)
PAGE_LABELS           = (_ICON_PROGRAM, _ICON_MATRIX, _ICON_INPUT, _ICON_OUTPUT, _ICON_TOOLS, _ICON_MONITOR, _ICON_SETTINGS)

CONTEXT_MENU_ITEMS    = ('rename', 'move backward', 'move forward', 'move to...')

_NR_IN_PORTS          = const(6)
_NR_OUT_PORTS         = const(6)
_LAYOUT_COLS          = const(4)
_CHORDS_COLS          = const(3)

BLANK_LABEL          = '[blank]'
DEFAULT_PROGRAM_NAME = 'incognito'

EMPTY_OPTIONS_BLANK   = ('',)
EMPTY_OPTIONS_1       = ('_',)
EMPTY_OPTIONS_2       = ('__',)
EMPTY_OPTIONS_3       = ('___',)
EMPTY_OPTIONS_4       = ('____',)
START_OPTION          = ('[start]',)

_ICON_CENTER          = chr(_FONT_FIRST_ZONE)
_ICON_RIM_EDGE        = chr(_FONT_FIRST_ZONE + 1)
_ICON_BOW             = chr(_FONT_FIRST_ZONE + 2)
_ICON_BELL            = chr(_FONT_FIRST_ZONE + 3)
_ICON_CHOKE           = chr(_FONT_FIRST_ZONE + 4)
_ICON_FOOT            = chr(_FONT_FIRST_ZONE + 5)
_ICON_LAYER_A         = chr(_FONT_FIRST_ZONE + 6)
_ICON_LAYER_B         = chr(_FONT_FIRST_ZONE + 7)
_ICON_LAYER_C         = chr(_FONT_FIRST_ZONE + 8)
_ICON_LAYER_D         = chr(_FONT_FIRST_ZONE + 9)
_SINGLE_OPT           = (EMPTY_OPTIONS_BLANK, EMPTY_OPTIONS_BLANK)
_PAD_OPT              = ((_ICON_CENTER, _ICON_RIM_EDGE), ('center', 'rim'))
_HIHAT_OPT            = ((_ICON_RIM_EDGE, _ICON_CENTER, _ICON_FOOT), ('edge', 'bow', 'foot'))
_CYMB_OPT             = ((_ICON_RIM_EDGE, _ICON_BOW, _ICON_BELL, _ICON_CHOKE), ('edge', 'bow', 'bell', 'choke'))
_MULTI_OPT            = ((_ICON_LAYER_A, _ICON_LAYER_B, _ICON_LAYER_C, _ICON_LAYER_D), ('layer A', 'layer B', 'layer C', 'layer D'))

_ICON_HARD            = chr(_FONT_FIRST_TRANSIENT) + chr(_FONT_FIRST_TRANSIENT + 1)
_ICON_SMOOTH_1        = chr(_FONT_FIRST_TRANSIENT + 2) + chr(_FONT_FIRST_TRANSIENT + 3)
_ICON_SMOOTH_2        = chr(_FONT_FIRST_TRANSIENT + 4) + chr(_FONT_FIRST_TRANSIENT + 5)
_ICON_LINEAR_TRANS    = chr(_FONT_FIRST_TRANSIENT + 6) + chr(_FONT_FIRST_TRANSIENT + 7)

_ICON_NEGATIVE_3      = chr(_FONT_FIRST_CURVE) + chr(_FONT_FIRST_CURVE + 1) + ' negative 3'
_ICON_NEGATIVE_2      = chr(_FONT_FIRST_CURVE + 2) + chr(_FONT_FIRST_CURVE + 3) + ' negative 2'
_ICON_NEGATIVE_1      = chr(_FONT_FIRST_CURVE + 4) + chr(_FONT_FIRST_CURVE + 5) + ' negative 1'
_ICON_LINEAR_CURVE    = chr(_FONT_FIRST_CURVE + 6) + chr(_FONT_FIRST_CURVE + 7) + ' linear    '
_ICON_POSITIVE_1      = chr(_FONT_FIRST_CURVE + 8) + chr(_FONT_FIRST_CURVE + 9) + ' positive 1'
_ICON_POSITIVE_2      = chr(_FONT_FIRST_CURVE + 10) + chr(_FONT_FIRST_CURVE + 11) + ' positive 2'
_ICON_POSITIVE_3      = chr(_FONT_FIRST_CURVE + 12) + chr(_FONT_FIRST_CURVE + 13) + ' positive 3'

_ICON_UP_RIGHT        = chr(_FONT_FIRST_PATTERN) + chr(_FONT_FIRST_PATTERN + 1)
_ICON_RIGHT_UP        = chr(_FONT_FIRST_PATTERN + 2) + chr(_FONT_FIRST_PATTERN + 3)
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

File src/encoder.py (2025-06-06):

''' Rotary encoder library for Cybo-Drummer - Humanize Those Drum Computers!
    https://github.com/HLammers/cybo-drummer
    Copyright (c) 2024-2025 Harm Lammers

    MIT licence:

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
    The above copyright notice and this permission notice shall be included in all copies or substantial portions of the Software.

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
    This code builds upon code fragments and ideas taken from:
        encoder_portable, copyright (c) 2017-2022 Peter Hinch, https://github.com/peterhinch/micropython-samples/tree/master/encoders
        encoder_timed, copyright (c) 2016-2021 Peter Hinch, https://github.com/peterhinch/micropython-samples/tree/master/encoders
        encoder.py asynchronous driver for incremental quadrature encoder, copyright (c) 2021-2024 Peter Hinch,
            https://github.com/peterhinch/micropython-async/blob/master/v3/primitives/encoder.py
    Acceleration algorithm taken from Adaptive User Input with a Rotary Encoder, marco_c, 20 April 2016, updated on 30 May 2017,
    https://arduinoplusplus.wordpress.com/2016/04/20/adaptive-user-input-with-a-rotary-encoder/'''

import micropython
from machine import Pin
import time
import math

_NONE               = const(-1)

_RANGE_DIVIDER      = const(80)
_RATE_DIVIDER       = const(10)
_MAX_RATE           = const(50)

_IRQ_RISING_FALLING = const(12) # Pin.IRQ_RISING | Pin.IRQ_FALLING

_RESET_DELAY        = const(10) # ms
_PROCESS_DELAY      = const(150) # ms

class Encoder:
    '''rotary encoder handling class; initiated by ui.__init__'''

    def __init__(self, pin_num_a, pin_num_b, value=0, div=1, max_val=_NONE):
        self.div = div
        self.max_val = max_val
        self.val = value * div
        self.multiplier = (max_val + 1) // _RANGE_DIVIDER
        ###### add Pin.PULL_UP if the rotary encoders have not external pull up resisters
        # self._pin_a = (_pin_a := Pin(pin_num_a, Pin.IN, Pin.PULL_UP))
        # self._pin_b = (_pin_b := Pin(pin_num_b, Pin.IN, Pin.PULL_UP))
        self._pin_a = (_pin_a := Pin(pin_num_a, Pin.IN))
        self._pin_b = (_pin_b := Pin(pin_num_b, Pin.IN))
        self.a = _pin_a()
        self.b = _pin_b()
        self.prev_val = _NONE
        self.prev_div_val = value
        self.out_val = value
        self.prev_out_val = value
        self.last_time = _NONE
        self.previous_time = _NONE
        self.last_value_out = _NONE
        _pin_a.irq(trigger=_IRQ_RISING_FALLING, handler=self._callback_a)
        _pin_b.irq(trigger=_IRQ_RISING_FALLING, handler=self._callback_b)

    def set(self, value: int, max_val: int = _NONE) -> None:
        '''sets rotary encoder value, range and increment; called by block .update functions, SelectBlock.set_options, TextEdit.open,
        *PopUp.draw, TriggerPopUp._update, ChordPopUp.open, Page._sub_page_selector and Page._initiate_nav_encoder'''
        self.val = value * self.div
        self.prev_val = _NONE
        self.prev_div_val = value
        self.out_val = value
        self.prev_out_val = value
        self.last_time = _NONE
        self.previous_time = _NONE
        self.last_value_out = _NONE
        if max_val != _NONE:
            self.max_val = max_val
            self.multiplier = (max_val + 1) // _RANGE_DIVIDER

    def value(self) -> int:
        '''return current encoder value if a new value is available, otherwise return _NONE; called by ui.process_encoder_input'''
        _time = time
        max_val = self.max_val
        if (val := self.val) == (prev_val := self.prev_val) or max_val == _NONE:
            if _time.ticks_diff(_time.ticks_ms(), self.last_value_out) > _RESET_DELAY:
                self.val = (val := self.prev_div_val * self.div)
                self.prev_val = val
            return _NONE
        prev_val = self.prev_val
        self.prev_val = val
        self.previous_time = (last_time := self.last_time)
        self.last_time = (current_time := _time.ticks_ms())
        if last_time == _NONE or _time.ticks_diff(current_time, last_time) < _PROCESS_DELAY:
            return _NONE
        div_val = math.ceil(val / self.div) if val > prev_val else math.floor(val / self.div)
        if not (d_val := div_val - self.prev_div_val):
            return _NONE
        self.prev_div_val = div_val
        out_val = self.out_val + (step := self._step() * d_val)
        if abs(step) == 1:
            out_val %= max_val + 1
        else:
            out_val = max(min(out_val, max_val), 0)
        if out_val == self.prev_out_val:
            return _NONE
        self.out_val = out_val
        self.prev_out_val = out_val
        self.last_value_out = current_time
        return out_val

    def close(self) -> None:
        self._pin_a.irq(None, 0)
        self._pin_b.irq(None, 0)
        
    def _callback_a(self, pin_a):
        '''callback for rotary a pin irq; called (assigned) by self.__init__'''
        if (a := int(pin_a())) == int(self.a):
            return
        self.a = a
        self.val -= 1 if a ^ self._pin_b() else -1

    def _callback_b(self, pin_b):
        '''callback for rotary b pin irq; called (assigned) by self.__init__'''
        if (b := pin_b()) == self.b:
            return
        self.b = b
        self.val += 1 if b ^ self._pin_a() else -1

    @micropython.viper
    def _step(self) -> int:
        '''return step size dependent on rotation speed; called by self.value'''
        if (delta := int(time.ticks_diff(self.last_time, self.previous_time))) == 0:
            return 1
        multiplier = int(self.multiplier)
        return 1 + multiplier * (1 << (int(min(_MAX_RATE, 1000 // delta)) // _RATE_DIVIDER)) - multiplier

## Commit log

2024-09-26 adding gerber files
2024-11-14 Revised knob and button behaviour
    * Values changed by turning the VAL knob or via MIDI learn are no longer processed immediately, but only after pressing the SEL button (which is the same knob), which makes the GUI much more responsive – a changed but not yet confirmed value is indicated by a purple box around the value
    * Changed behaviour of the PAGE button from press and hold to toggling on and off page change mode – this makes single hand operation easier
    * Changed behaviour of the TRIGGER button from press and hold to select trigger to long-press to open trigger selection pop-up
    * Added shortcut to select program via a pop-up which shows when long-pressing the PAGE button
    * GUI effic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
    [button.py, data.py, main_loops.py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]
2024-11-16 Update ui.py
    Disable trigger button when in page select mode
2025-06-06 Uploading everything
    [B14_Drumlogue Slot Machine.json, Cybo-Drummer case bottom part v3.0.stl, Cybo-Drummer case top part v3.0.stl]

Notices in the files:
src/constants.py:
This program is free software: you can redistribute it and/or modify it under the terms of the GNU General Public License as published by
